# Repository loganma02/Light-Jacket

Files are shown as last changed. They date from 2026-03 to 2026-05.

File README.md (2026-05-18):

# Light Jacket
Person wearing light jacket glowing green while standing in alley

In this project I set out to make a jacket for a costume with which I could change colors and pulse lights in a pattern,
[WLED](https://github.com/WLED/WLED) allowed for app-based control and minimal fiddling once powered on.

## <ins>PCB Update Mid May 2026 </ins>
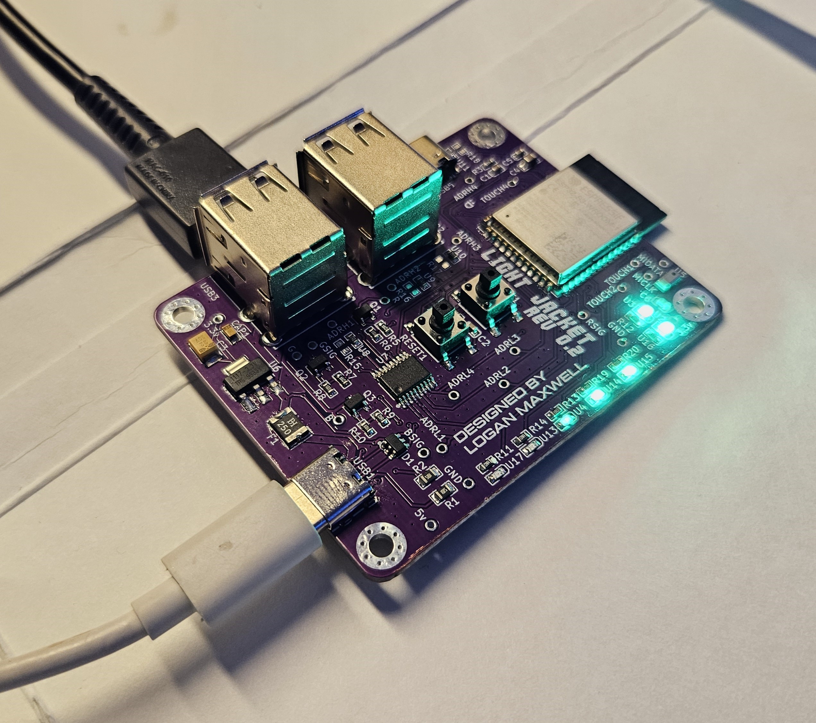
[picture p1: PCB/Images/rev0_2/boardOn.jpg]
light jacket board with lights on (https://youtu.be/194a6y9pxL4)

[See it in action here!](https://youtu.be/194a6y9pxL4)
<table>
  <tr>
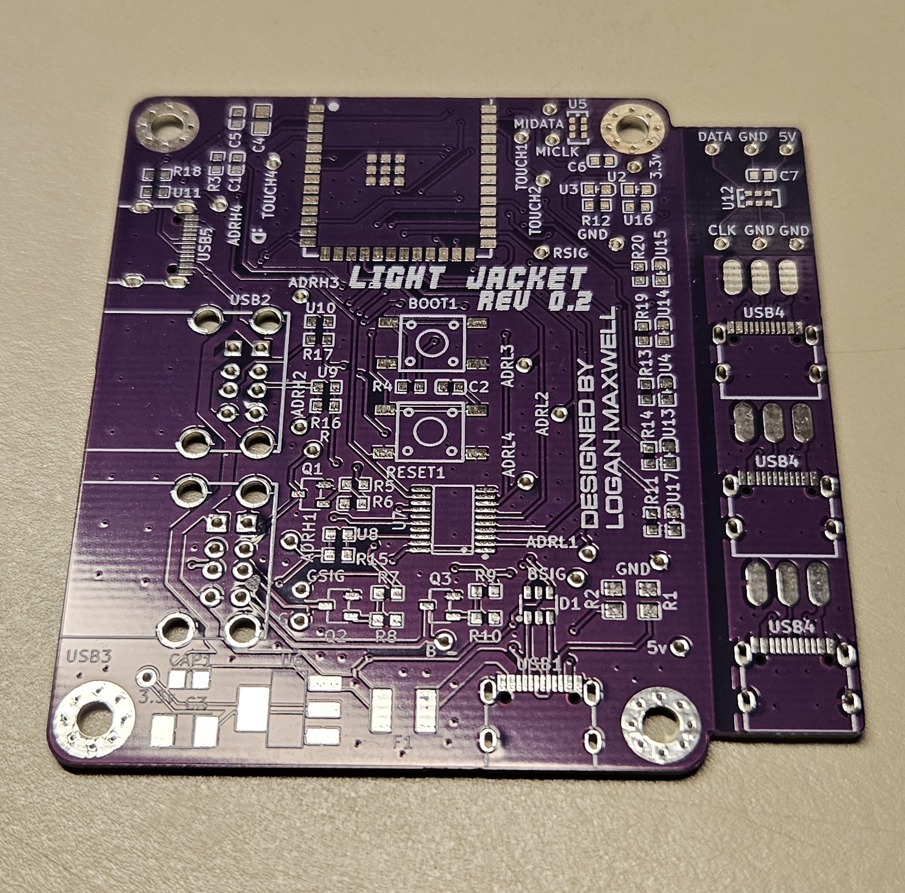
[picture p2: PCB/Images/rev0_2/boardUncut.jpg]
New board with breakouts attached
    <td></td>
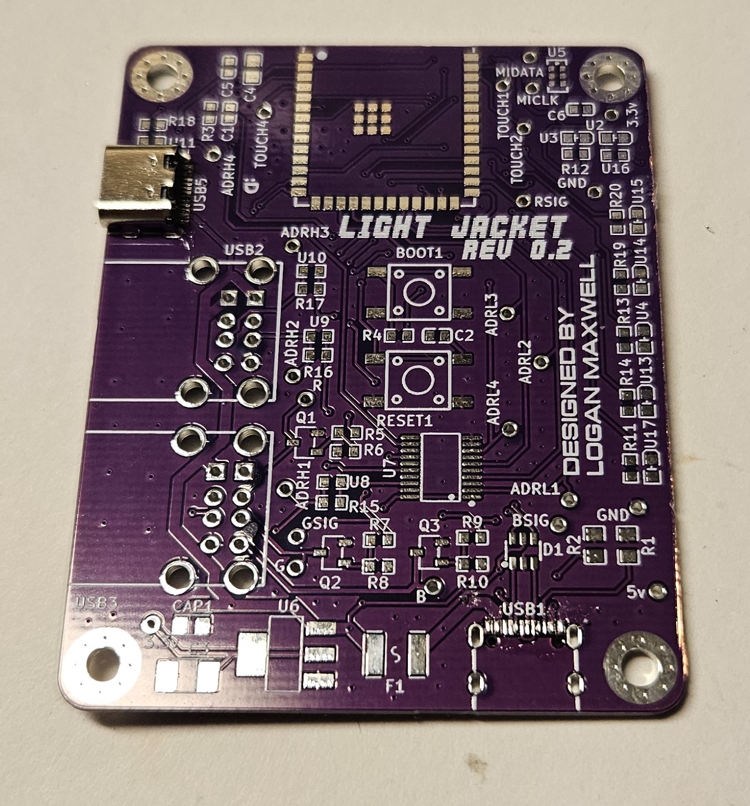
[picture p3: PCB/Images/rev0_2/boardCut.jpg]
New board with breakouts removed
    <td></td>
  </tr>
</table>

This revision arrived and looks great with the purple silkscreen. Trying the score and snap proved difficult due to the copper pour over the region, but tin shears made easy work of cutting off the breakout boards.

With the breakout board I made to attach to an addressable strip using USB-C I flipped the power and ground connections from what I intended, I wanted to sandwich the solder between the board and the strip. Nonetheless it feels much sturdier than soldering individual wires cut from the inside of a cable, and looks a lot cleaner too.
The USB-C connector on the board for output works quite well, if I switch away from USB-A I could shrink the vertical footprint too.

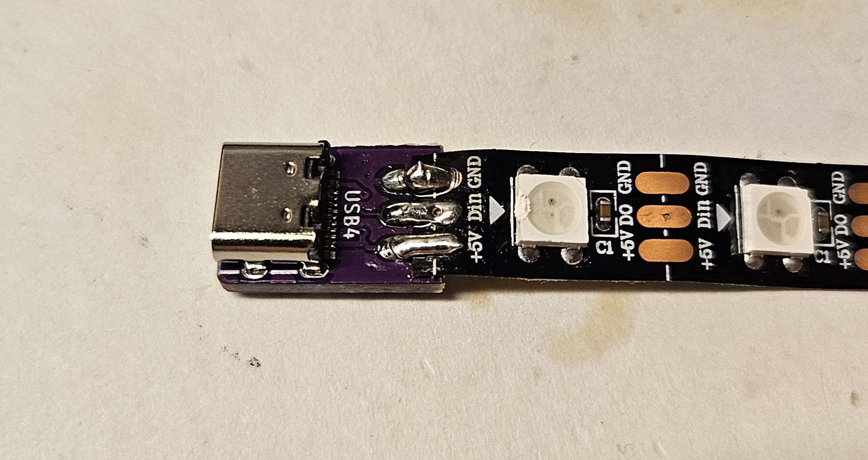
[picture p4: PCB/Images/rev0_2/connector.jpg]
closeup of usbc breakout board


The microphone remains to be working even with an added decoupling capacitor near its power input. There is a breakout board where I'll use a different microcontroller to test its function, perhaps it just isn't compatible with WLED as is.

The 5 onboard LEDs available to control came only from having an abundance of GPIO pins leftover, but I find them to be a nice touch. WLED can easily bundle them into a segment to display effects. Perhaps they could be used to show information to justify their placement beyond aesthetics, but even without I think the small increase in BOM cost is worth it.

## <ins>PCB Update Mid April 2026 </ins>
Taking into account some of the problems with the board as it was:
* Addressable LED control not working as expected
* [No resistor on the LED data lines](https://quinled.info/data-signal-cable-conditioning/)
* No testing pads for 5v LED signals
* Microphone not working
* USB-A ports too close together for thick plugs
* UCB-C port in wrong corner for intended use with power bank
* Only one controllable onboard LED
* Unrounded corners

I decided to design another revision, this time in KiCad to further my skills with that software. Using the [LCSC library loader](https://github.com/dsa-t/jlc-kicad-lib-loader) addon bringing footprints and step models from my EasyEDA design was easy, and reconstructing the schematic in KiCad took only a little while.
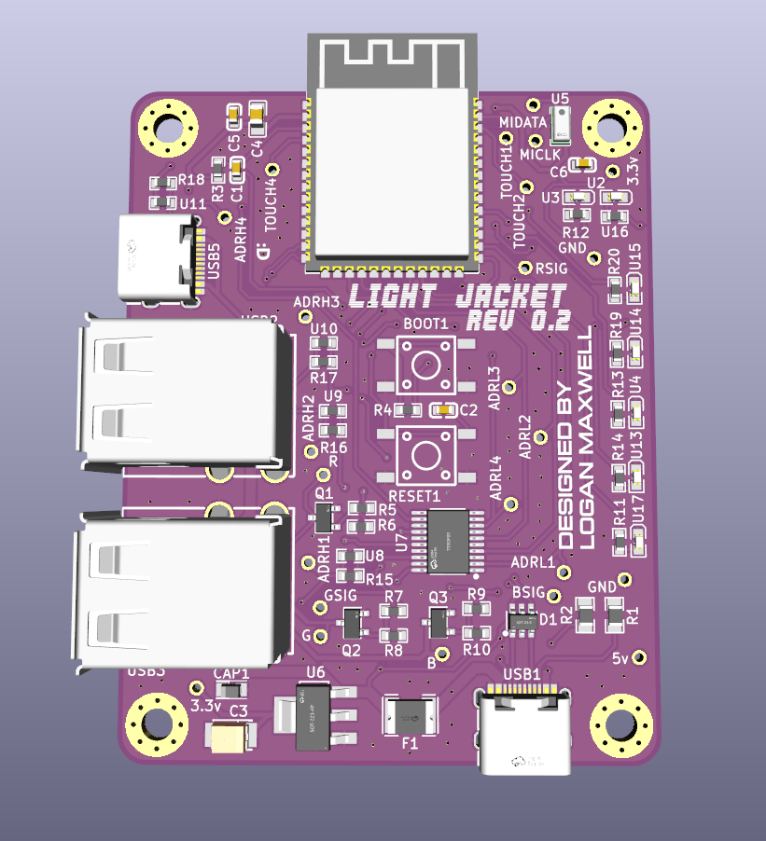
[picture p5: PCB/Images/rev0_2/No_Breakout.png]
No breakout version of board


I realized while designing I wanted breakout boards for testing the microphone on its own, as well as USB-C boards with pads that match the size and layout of the strip. I used mousebites provided by [Panelization.pretty](https://github.com/madworm/Panelization.pretty) to add those breakouts to the side of the main board:
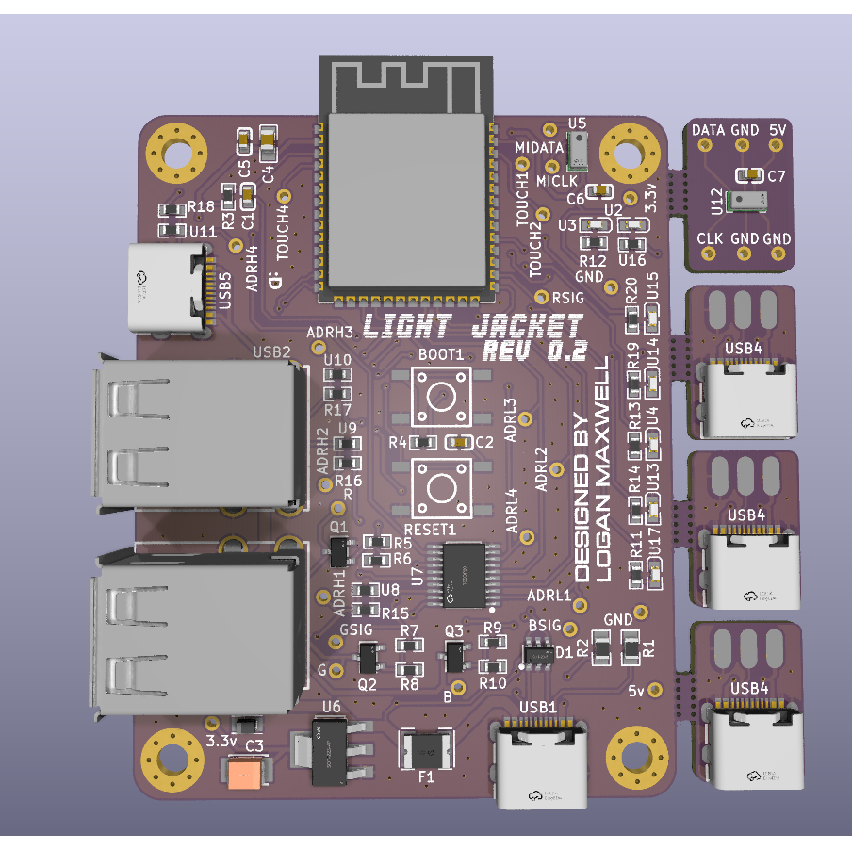
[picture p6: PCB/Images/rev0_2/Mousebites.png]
Mousebites version of the board


Unfortunately this was rejected by JLCPCB as containing too many individual designs to quality for lower manufacturing costs, likely due to extra care needed in handling panelized boards. I instead decided to make the breakouts contained within the same shape as the main board (which JLCPCB did accept) and will use the score-and-snap method to separate them when it arrives.
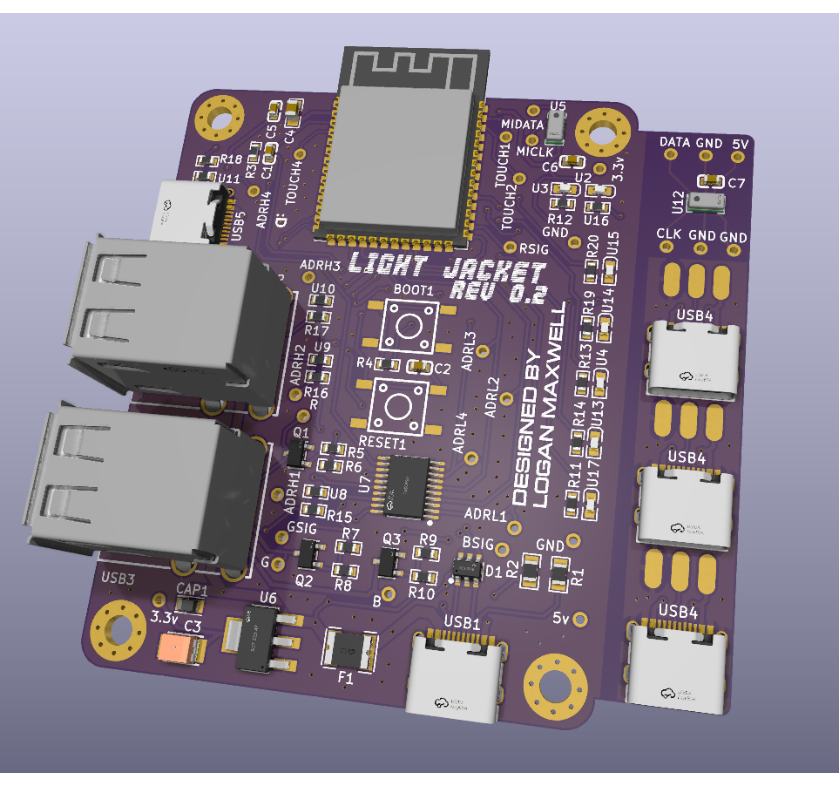
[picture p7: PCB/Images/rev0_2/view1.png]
View 1

<table>
  <tr>
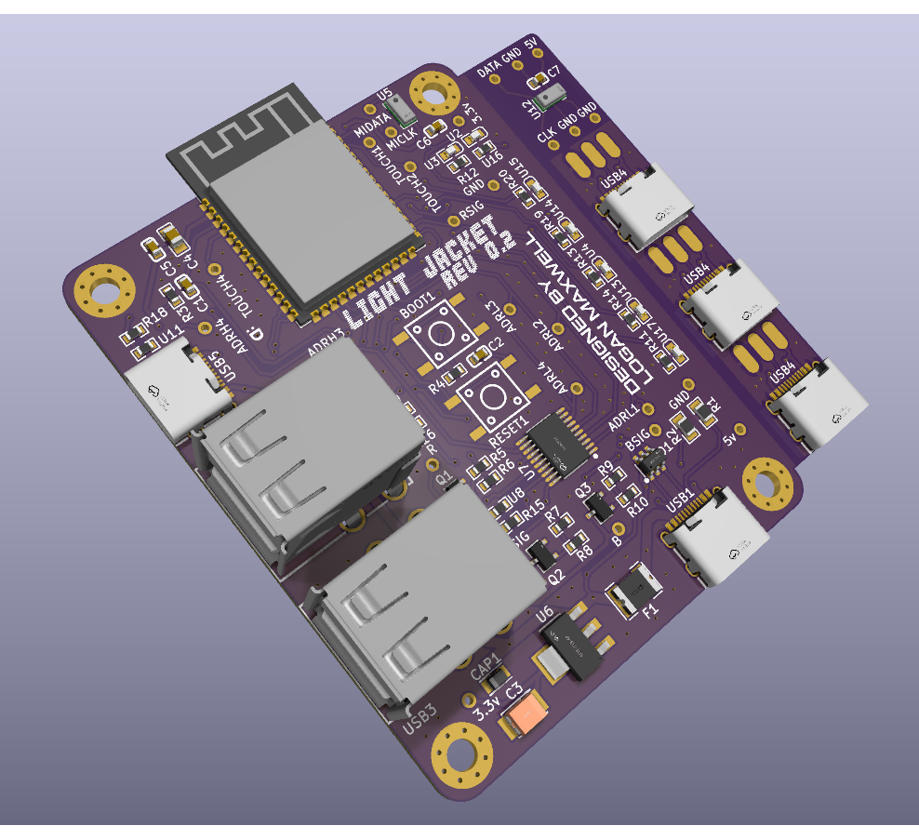
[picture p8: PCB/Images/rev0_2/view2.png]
View 2
    <td></td>
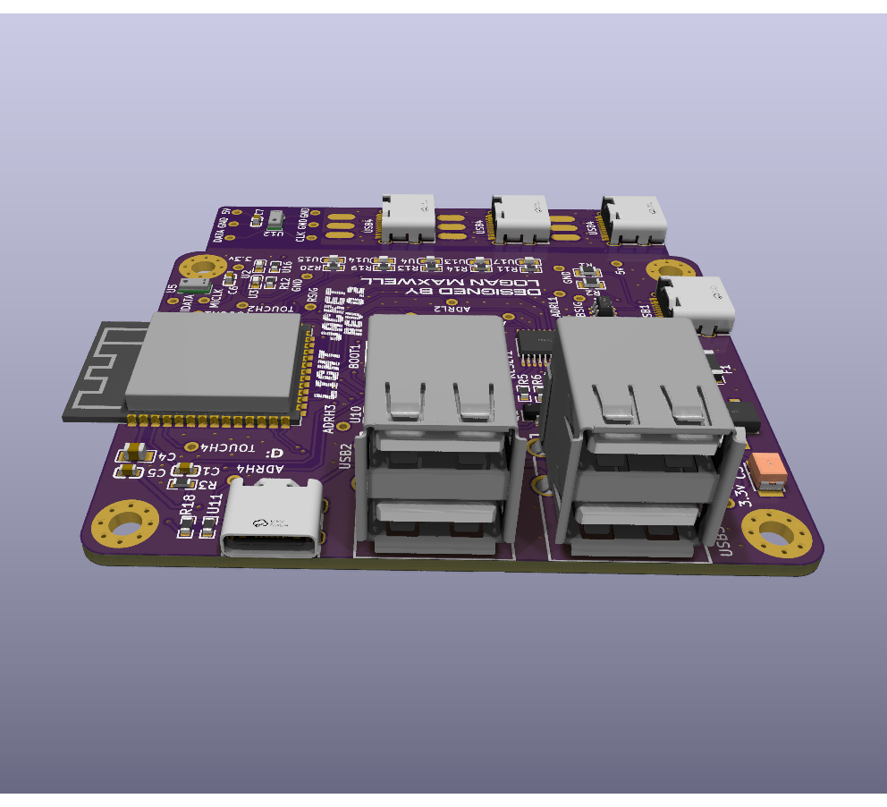
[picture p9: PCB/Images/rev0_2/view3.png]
View 3
    <td></td>
  </tr>
</table>

## <ins>PCB Update Early April 2026 </ins>
The first revision of the PCB arrived and came out of JLCPCB fab better than expected. I was a little bit worried about silkscreen readability as text 0.15mm stroke width was ever so slightly below their [manufacturing capabilities](https://jlcpcb.com/capabilities/pcb-capabilities), but it came through perfectly readable.
<table>
  <tr>
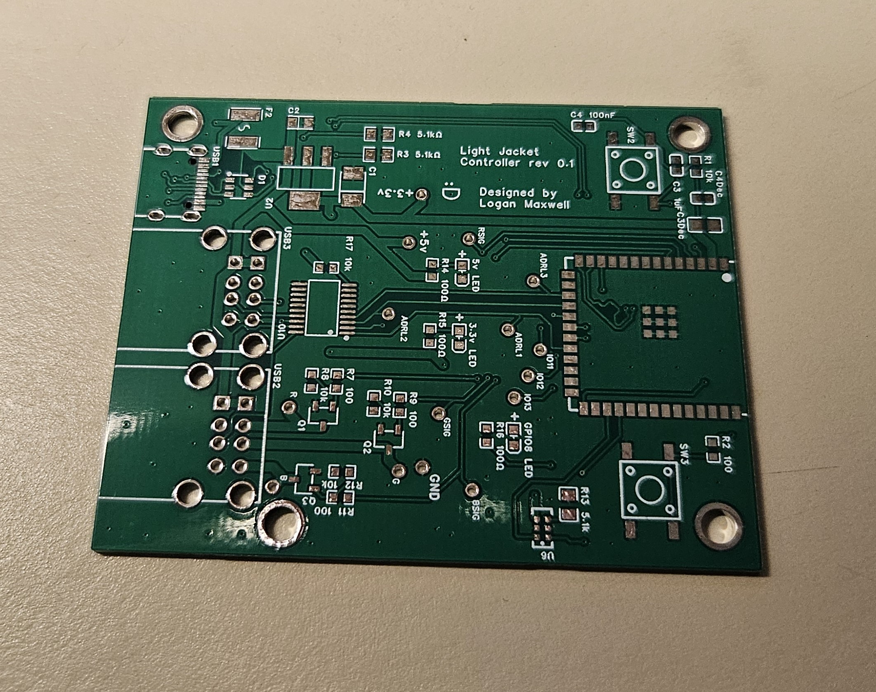
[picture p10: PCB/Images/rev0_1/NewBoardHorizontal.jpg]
New board place horizontally
    <td></td>
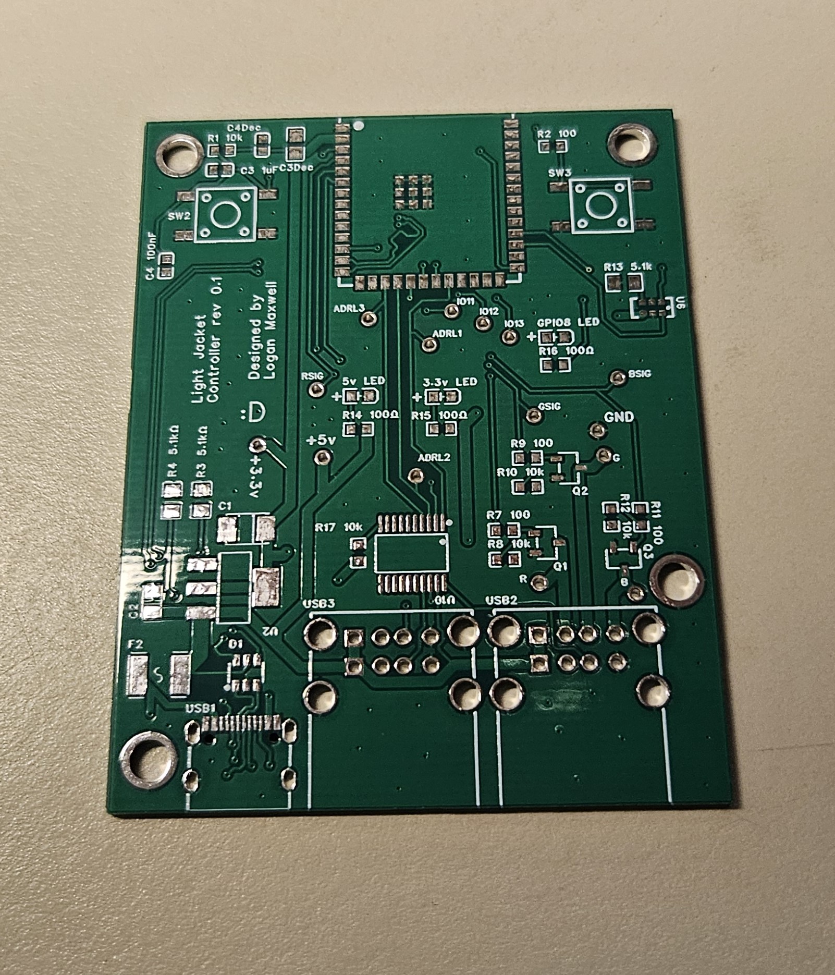
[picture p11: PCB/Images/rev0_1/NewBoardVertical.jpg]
New board place vertically
    <td></td>
  </tr>
</table>

Soldering was relatively easy if not time-consuming, as this was my first experience with hor air reflow soldering for SMD components.
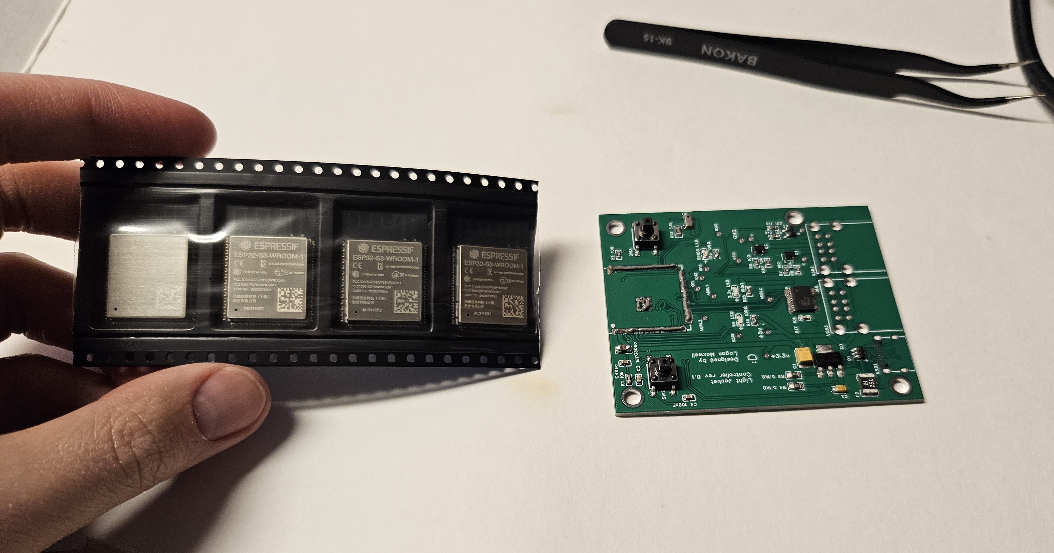
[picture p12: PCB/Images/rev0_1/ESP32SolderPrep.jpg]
Ready to solder ESP32

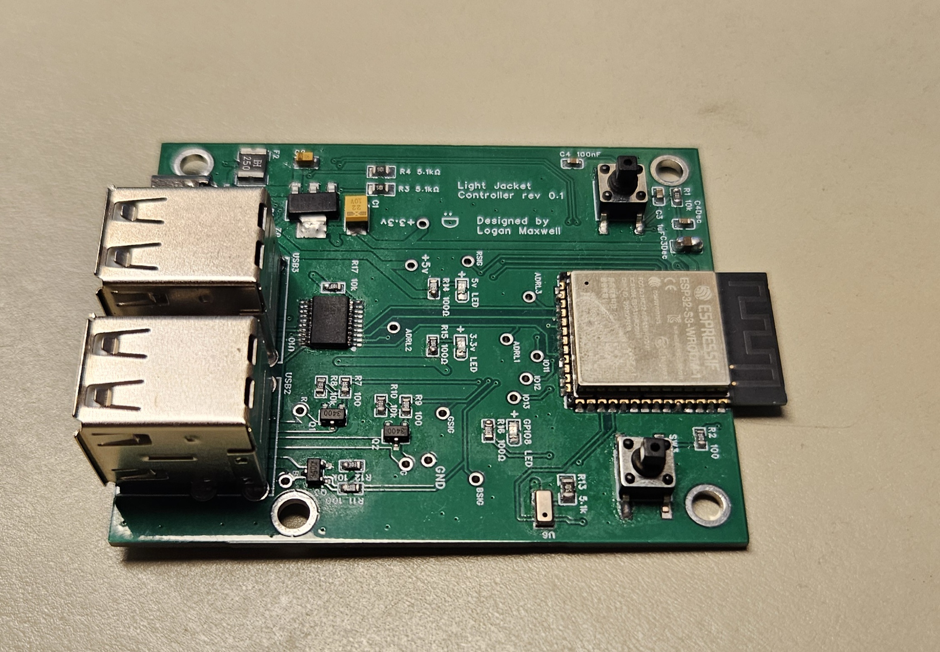
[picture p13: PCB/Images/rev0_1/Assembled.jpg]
Assembled Board


Once assembled I could verify that both my 3.3v and 5v power rails were functioning with both LED's lighting up, and went ahead and installed WLED v16 on it through USB. The PWM RGB strip control worked without a hitch, and could drive an LED strip with a common voltage and individual color grounds.
Working with single color

I did run into a problem with addressable strip control where I would get a randomly blinking mess. See it here:
<details> 
  <summary>Caution: Flashing Lights</summary>

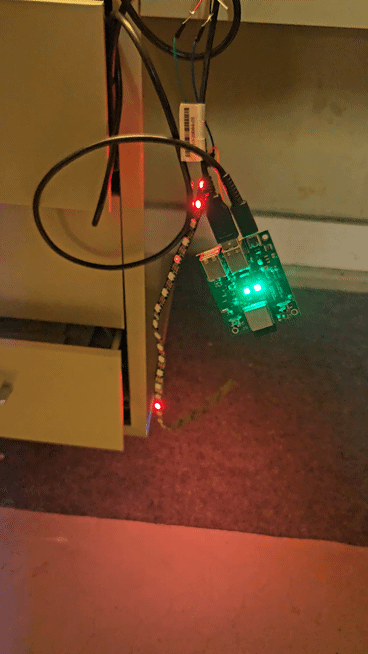
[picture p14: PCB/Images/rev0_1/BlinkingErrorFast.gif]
Addressable led control flashing error
    
</details>

I don't have an oscilloscope to be able to test and see what's happening to the signal, but some research leads me to believe it might have to do with the way I'm using the TXS0108EPWR for level shifting. It seems to be designed more for high-speed onboard signal shifting whose output runs [less than 6 inches](https://learn.sparkfun.com/tutorials/level-shifter---8-channel-txs0108e-hookup-guide/all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,level%20shifters.).
The bi-directionality of the TXS0108EPWR could mean that it's picking up noise on the "output" that triggers it to switch directions and start communicating in the wrong direction.
Letting the supply voltage and ground travel though a USB cable while connecting the data line straight to a 3.3v signal output (which should be too low for the WS2812b) from the ESP32 made it work no problem.

## <ins>PCB Update March 2026 </ins>
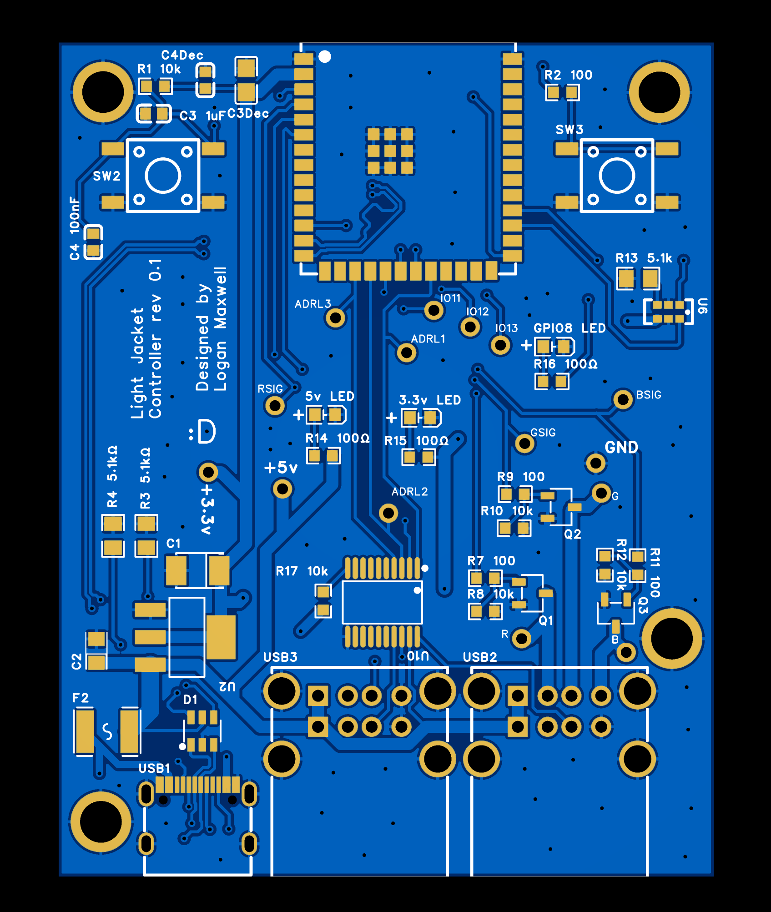
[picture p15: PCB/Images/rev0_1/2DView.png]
PCB 2D View

Currently awaiting delivery of a prototype PCB board for this jacket. Using an ESP32-S3 and a digital microphone to make audio reactivity possible with WLED.
Chose to use USB-C for programming and power due to availability of cables, and the USB-A plug (but not the full standard) for the connection to the lights. Exploring USB-C plug or magnetic connectors for this purpose.
Gerber files can be found [here](PCB/LightJacketV0.1.zip).
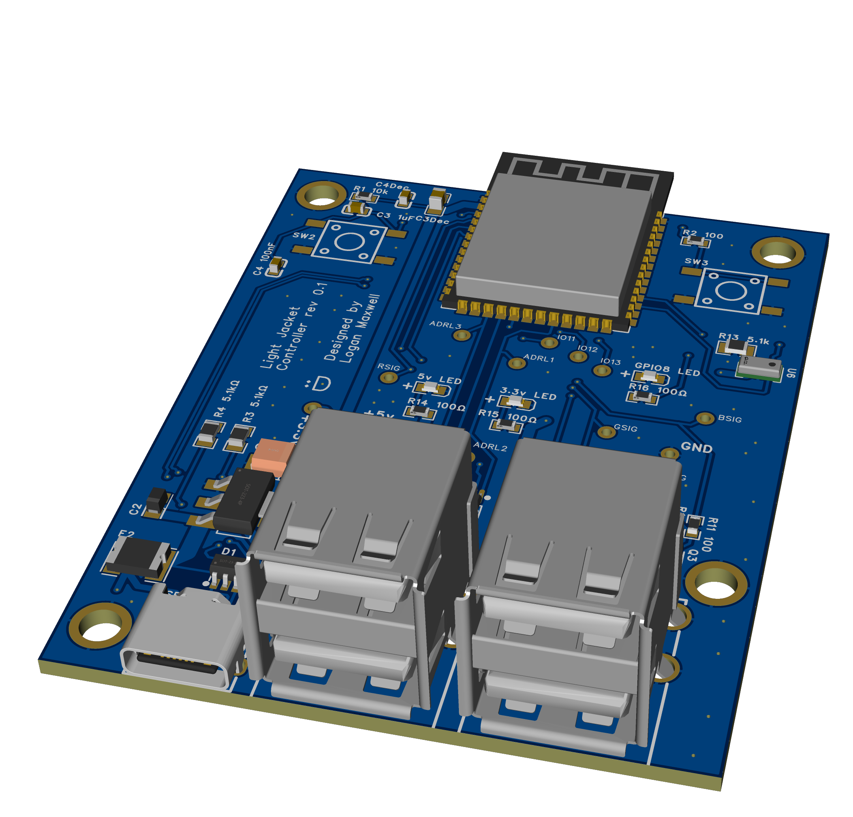
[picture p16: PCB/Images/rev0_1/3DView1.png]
PCB 3D View 1

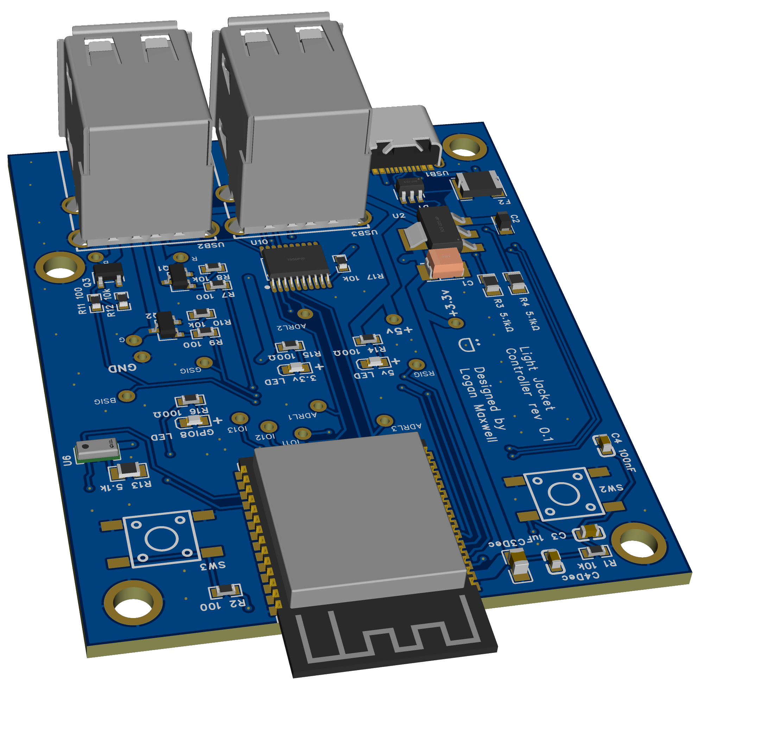
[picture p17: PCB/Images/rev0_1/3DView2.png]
PCB 3D View 2


## Jacket Construction
Jacket unfurled showing strip and circuit board

The strip runs hidden along the inside next to the zipper for an ambient lighting effect, and visible around the collar for the exposed design choice.
The battery and circuit board tuck into an existing pocket on the inside.

Inside of jacket showing LED strip sewn in
I decided to sew in the strip for durability rather than use adhesive, and tried to match existing seam lines.

## Circuitry
I used an ESP8266 and a single color RGB LED strip as that's what I had on hand, but opting for a ESP32 increases options available for WLED, and addressable LED strips allow for more impressive patterns to be displayed.
WLED has an option to control single color strips with PWM signals for each RGB channel, and I fed signal each into a transistor to boost the power for that channel.
Power is supplied by a phone battery bank connected by a USB cable spliced to provide 5V to the ESP as well as each transistor. 
3 transistors visible on perfboard with wires visible leading to power bank and LED strip
*Transistor side of perfboard*

ESP8266 soldered to perfboard
*ESP8266 on perfboard*

## Next steps
I would like to upgrade the microcontroller to an ESP32 and add a microphone, as WLED has better support for audio reactivity on that board.
Ultimately want the jacket to react to sounds, such as pulsing along to the beat of music on a dancefloor, or visually alerting the user to a dangerously loud environment.

## Images
Jacket worn, illuminated green
Jacket worn, illuminated blue
Light Jacket illuminated blue laid out on table

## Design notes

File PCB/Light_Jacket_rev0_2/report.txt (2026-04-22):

Plotted to 'C:\Users\logan\Documents\KiCad\ESP32 Tutorial S3\Light_Jacket_rev0_2\Output\Light_Jacket_rev0_2-F_Cu.gbr'.
Plotted to 'C:\Users\logan\Documents\KiCad\ESP32 Tutorial S3\Light_Jacket_rev0_2\Output\Light_Jacket_rev0_2-B_Cu.gbr'.
Plotted to 'C:\Users\logan\Documents\KiCad\ESP32 Tutorial S3\Light_Jacket_rev0_2\Output\Light_Jacket_rev0_2-F_Paste.gbr'.
Plotted to 'C:\Users\logan\Documents\KiCad\ESP32 Tutorial S3\Light_Jacket_rev0_2\Output\Light_Jacket_rev0_2-B_Paste.gbr'.
Plotted to 'C:\Users\logan\Documents\KiCad\ESP32 Tutorial S3\Light_Jacket_rev0_2\Output\Light_Jacket_rev0_2-F_Silkscreen.gbr'.
Plotted to 'C:\Users\logan\Documents\KiCad\ESP32 Tutorial S3\Light_Jacket_rev0_2\Output\Light_Jacket_rev0_2-B_Silkscreen.gbr'.
Plotted to 'C:\Users\logan\Documents\KiCad\ESP32 Tutorial S3\Light_Jacket_rev0_2\Output\Light_Jacket_rev0_2-F_Mask.gbr'.
Plotted to 'C:\Users\logan\Documents\KiCad\ESP32 Tutorial S3\Light_Jacket_rev0_2\Output\Light_Jacket_rev0_2-B_Mask.gbr'.
Plotted to 'C:\Users\logan\Documents\KiCad\ESP32 Tutorial S3\Light_Jacket_rev0_2\Output\Light_Jacket_rev0_2-Edge_Cuts.gbr'.
Created Gerber job file 'C:\Users\logan\Documents\KiCad\ESP32 Tutorial S3\Light_Jacket_rev0_2\Output\Light_Jacket_rev0_2-job.gbrjob'.
Info: Done.
Info: Done.

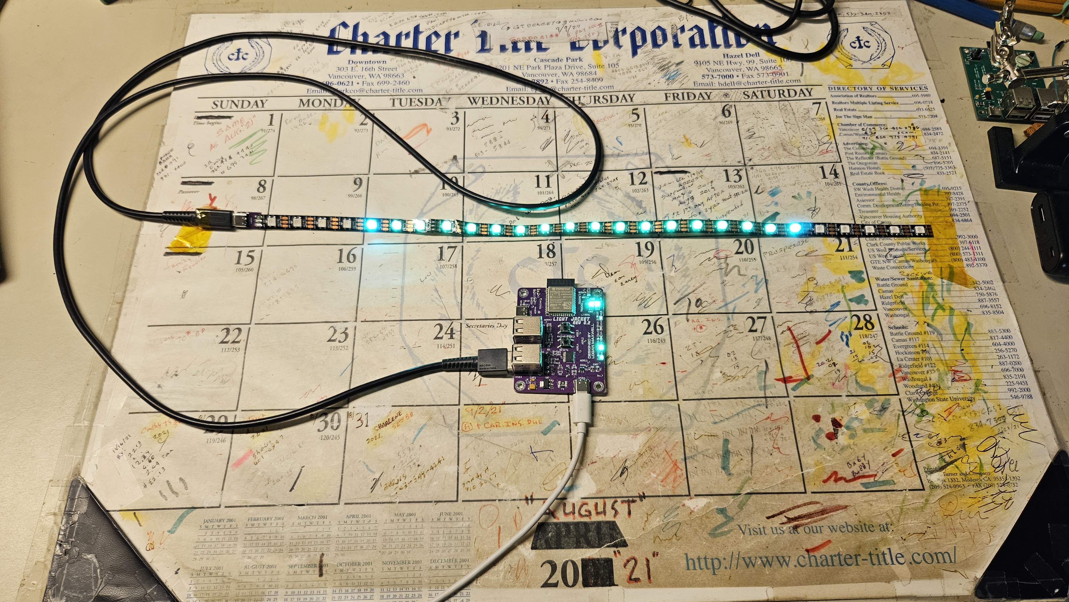
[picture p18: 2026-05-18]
PCB/Images/rev0_2/overview.jpg

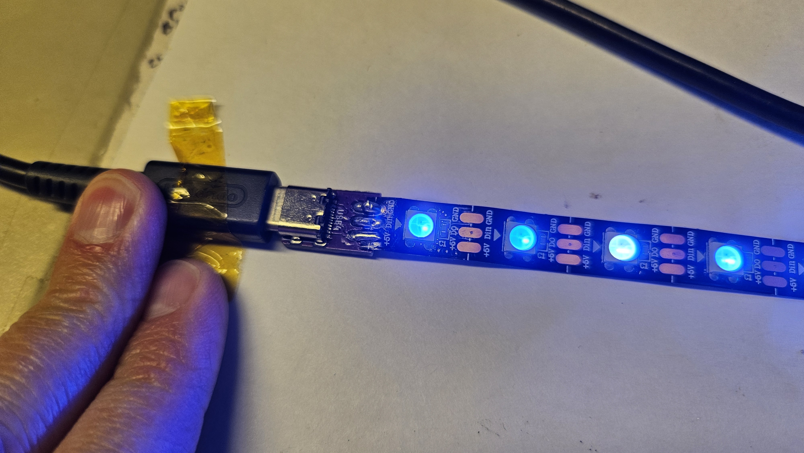
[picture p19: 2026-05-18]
PCB/Images/rev0_2/connectorLit.jpg

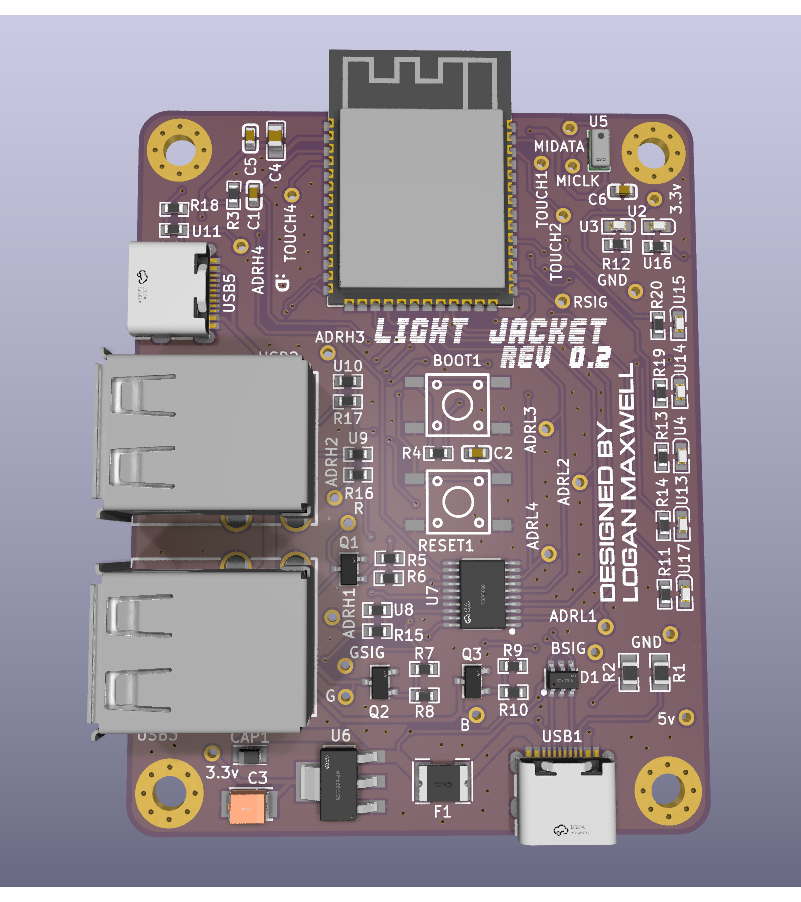
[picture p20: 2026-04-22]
PCB/Images/rev0_2/No_Breakout2.png

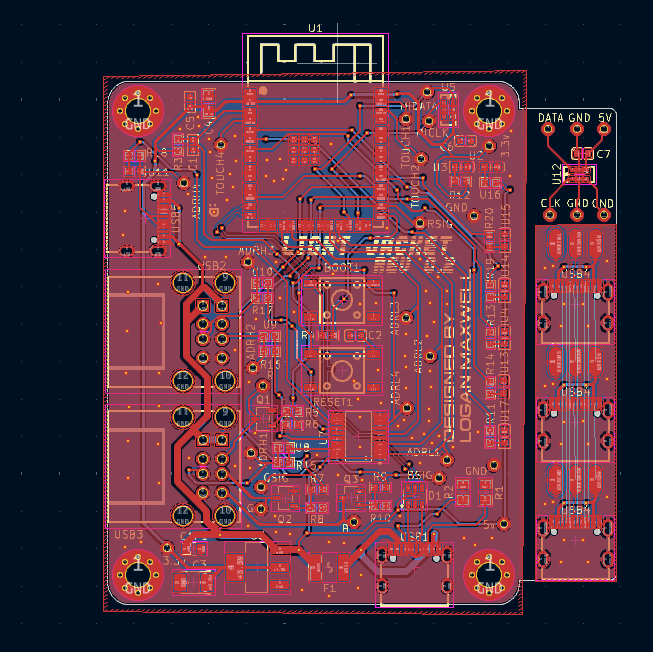
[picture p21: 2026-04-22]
PCB/Images/rev0_2/KicadLayout.png

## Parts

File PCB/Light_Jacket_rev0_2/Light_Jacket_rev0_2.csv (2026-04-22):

Reference | Qty | Value | DNP | Exclude from BOM | Exclude from Board | Footprint | Datasheet | Supplier Part | LCSC Part Name
BOOT1,RESET1 | 2 | ~ |  |  |  | EasyEDA_Lib:SW-SMD_4P-L6.0-W6.0-P4.50-LS9.0-H7.3 | https://item.szlcsc.com/datasheet/HX-6x6x7.3-TP%2520FT%2520square%2520button/51650213.html | C49234152 | 6*6*7.3mm贴片 方头 轻触开关
C1 | 1 | 1uF |  |  |  | EasyEDA_Lib:C0603 | https://item.szlcsc.com/datasheet/CL10A105KB8NNNC/16531.html | C15849 | 1uF ±10% 50V
C2,C5,C6,C7 | 4 | 100nF |  |  |  | EasyEDA_Lib:C0603 | https://item.szlcsc.com/datasheet/CC0603KRX7R9BB104/15331.html | C14663 | 100nF ±10% 50V
C3 | 1 | 22uF |  |  |  | EasyEDA_Lib:CAP-SMD_L3.5-W2.8 | https://item.szlcsc.com/datasheet/CA45-B-10V-22uF-K/151738.html | C140412 | 22uF ±10% 10V
C4 | 1 | 22uF |  |  |  | EasyEDA_Lib:C0805 | https://item.szlcsc.com/datasheet/CL21A226MAYNNNE/631473.html | C602037 | 22uF ±20% 25V
CAP1 | 1 | 10uF |  |  |  | EasyEDA_Lib:CAP-SMD_L2.0-W1.3-FD | https://item.szlcsc.com/datasheet/CA45-P-10V-10uF-K/940979.html | C879894 | 10uF ±10% 10V
D1 | 1 | ~ |  |  |  | EasyEDA_Lib:SOT-23-6_L2.9-W1.6-P0.95-LS2.8-BL | https://item.szlcsc.com/datasheet/USBLC6-2SC6/2973336.html | C2827654 | ESD，可防30kV静电
F1 | 1 | ~ |  |  |  | EasyEDA_Lib:F1812 | https://item.szlcsc.com/datasheet/BSMD1812-250-8V/1039127.html | C960027 | 8V 2.5A 1812自恢复
Q1,Q2,Q3 | 3 | ~ |  |  |  | EasyEDA_Lib:SOT-23-3_L3.0-W1.6-P1.90-LS2.8-BR | https://item.szlcsc.com/datasheet/AO3400A/5925703.html | C5224194 | N沟道,电流:5.8A,耐压:30V
R1,R2 | 2 | 5.1kΩ |  |  |  | EasyEDA_Lib:R0805 | https://item.szlcsc.com/datasheet/0805W8F5101T5E/28584.html | C27834 | 5.1kΩ ±1% 125mW 厚膜电阻
R3,R6,R8,R10 | 4 | 10kΩ |  |  |  | EasyEDA_Lib:R0603 | https://item.szlcsc.com/datasheet/FRC0603J103%2520TS/3266960.html | C2930027 | 10kΩ ±5% 100mW 厚膜电阻
R4,R5,R7,R9,R11,R12,R13,R14,R19,R20 | 10 | 100Ω |  |  |  | EasyEDA_Lib:R0603 | https://atta.szlcsc.com/upload/public/pdf/source/20180316/70C0E2BDAE7FCC62C531A5A58D202EE1.pdf | C105588 | 厚膜电阻 100Ω ±1% 100mW
R15,R16,R17,R18 | 4 | 33Ω |  |  |  | EasyEDA_Lib:R0603 | https://item.szlcsc.com/datasheet/RC0603FR-0733RL/109880.html | C108661 | 厚膜电阻 33Ω ±1% 100mW
TP1,TP2,TP3,TP4,TP5,TP6,TP7,TP8,TP9,TP10,TP11,TP12,TP13,TP14,TP15,TP16,TP17,TP18,TP19,TP20,TP21,TP22,TP23,TP24,TP25,TP26,TP27,TP28,TP29,TP30 | 30 | TestPoint |  |  |  | CustomLibrary:EasyEDA Pad | ~
U1 | 1 | 2.4GHz |  |  |  | EasyEDA_Lib:WIRELM-SMD_ESP32-S3-WROOM-1 | https://item.szlcsc.com/datasheet/ESP32-S3-WROOM-1-N16R2/3198303.html | C2913205 | 不带固件 通用型Wi-Fi+低功耗蓝牙MCU模组
U2,U3,U4,U13,U14,U15,U17 | 7 | ~ |  |  |  | EasyEDA_Lib:LED0603-FD | https://item.szlcsc.com/datasheet/YLED0603G/20555405.html | C19273151 | 翠绿色 独立二极管
U5,U12 | 2 | ~ |  |  |  | EasyEDA_Lib:MIC-SMD_6P-L4.0-W2.0_LMD4020T261-OC3 | https://item.szlcsc.com/datasheet/MSM261DGT003/50474176.html | C48227730 | 1.8V 26dB
U6 | 1 | ~ |  |  |  | EasyEDA_Lib:SOT-223-3_L6.5-W3.4-P2.30-LS7.0-BR | https://item.szlcsc.com/datasheet/AMS1117-3.3/19384486.html | C18212698 | 1A低压差线性稳压器
U7 | 1 | ~ |  |  |  | EasyEDA_Lib:TSSOP-20_L6.5-W4.4-P0.65-LS6.4-BL | https://item.szlcsc.com/datasheet/74HCT245PW/54938180.html | C52140501 | 74HCT245PW
U8,U9,U10,U11,U16 | 5 | 249Ω |  |  |  | EasyEDA_Lib:R0603 |  | C2933176 | 249Ω ±1% 100mW 厚膜电阻
USB1,USB4,USB5 | 3 | ~ |  |  |  | EasyEDA_Lib:USB-C_SMD-TYPE-C-31-M-12 | https://item.szlcsc.com/datasheet/USB-TYPE-C-018/3252507.html | C2927038 | Type-C 母 卧贴
USB2,USB3 | 2 | ~ |  |  |  | EasyEDA_Lib:USB-A-TH_AF-SS-JB17.6 | https://item.szlcsc.com/datasheet/AF%2520SS-JB17.6/458828.html | C456021 | Type-A弯插双层母座
C108661 |  |  |  |  |  |  |  | C105588
0 |  |  |  |  |  |  |  | C140412
C52140501 |  |  |  |  |  |  |  | C14663
C2933176 |  |  |  |  |  |  |  | C15849
 |  |  |  |  |  |  |  | C17206
 |  |  |  |  |  |  |  | C18212698
 |  |  |  |  |  |  |  | C19273151
 |  |  |  |  |  |  |  | C27834
 |  |  |  |  |  |  |  | C2827654
 |  |  |  |  |  |  |  | C2913205
 |  |  |  |  |  |  |  | C2927038
 |  |  |  |  |  |  |  | C2930027
 |  |  |  |  |  |  |  | C456021
 |  |  |  |  |  |  |  | C48227730
 |  |  |  |  |  |  |  | C49234152
 |  |  |  |  |  |  |  | C5224194
 |  |  |  |  |  |  |  | C602037
 |  |  |  |  |  |  |  | C879894
 |  |  |  |  |  |  |  | C960027

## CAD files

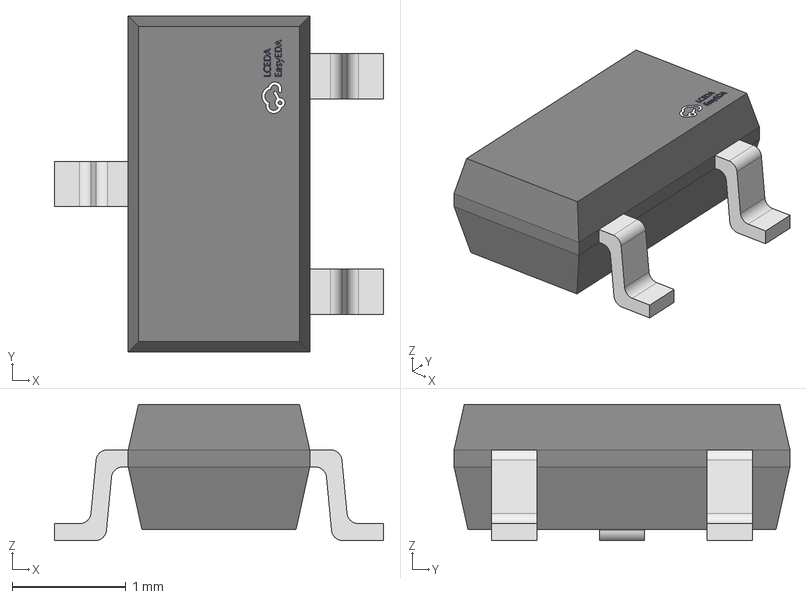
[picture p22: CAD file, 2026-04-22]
PCB/Light_Jacket_rev0_2/EASYEDA_MODELS/SOT-23-3_L3.0-W1.6-P1.90-LS2.8-BR.step
2.90 x 2.96 x 1.20 mm

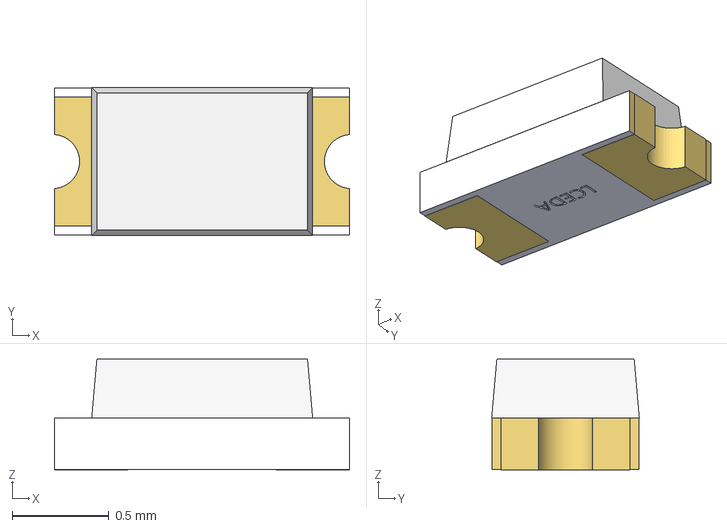
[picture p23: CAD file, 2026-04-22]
PCB/Light_Jacket_rev0_2/EASYEDA_MODELS/LED0603_Inf.step
1.52 x 0.762 x 0.571 mm

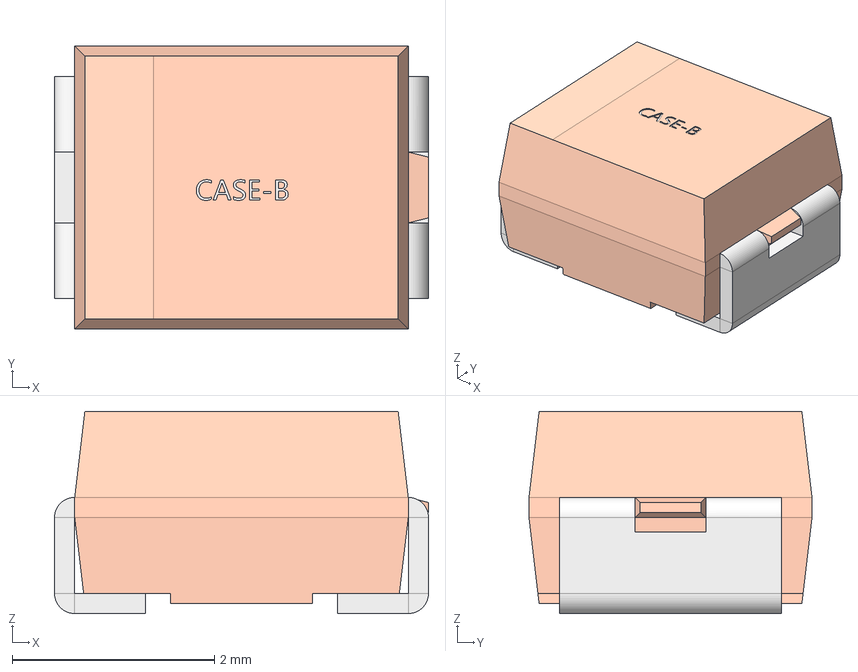
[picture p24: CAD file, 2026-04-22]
PCB/Light_Jacket_rev0_2/EASYEDA_MODELS/CASE-B_L3.5-W2.8-H1.9.step
3.70 x 2.80 x 2.00 mm

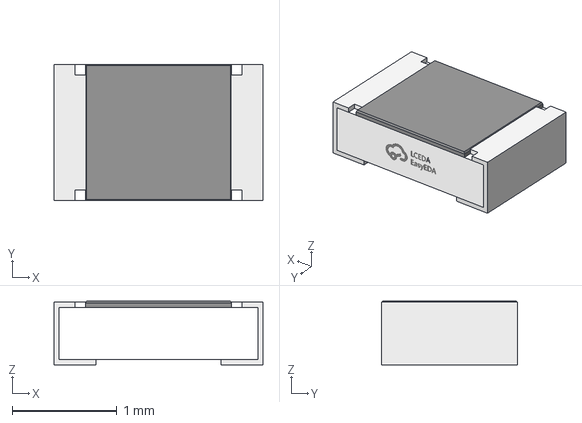
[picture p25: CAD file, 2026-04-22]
PCB/Light_Jacket_rev0_2/EASYEDA_MODELS/R0805_L2.0-W1.3-H0.6.step
2.00 x 1.30 x 0.61 mm

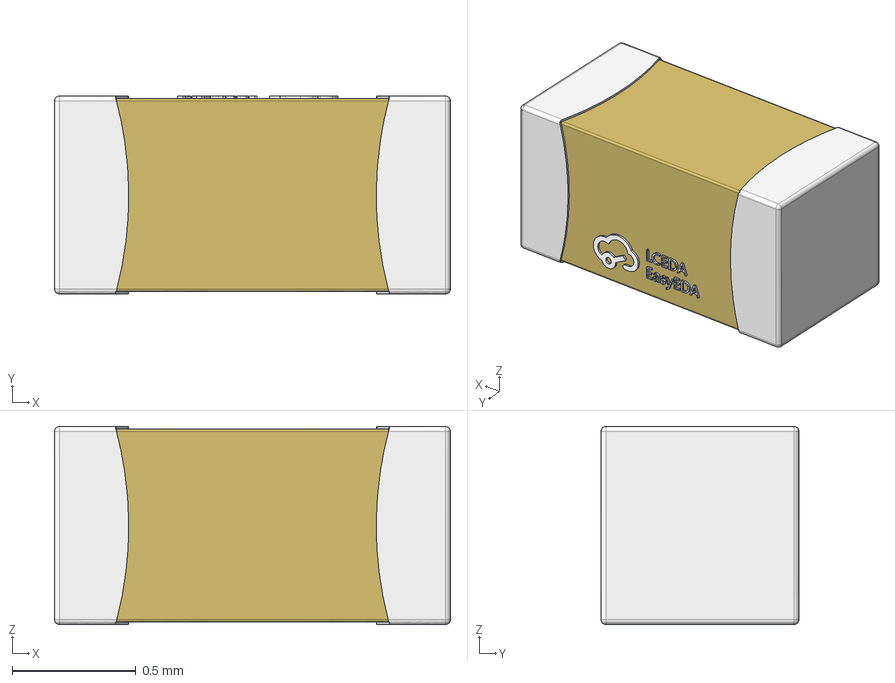
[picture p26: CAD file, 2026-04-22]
PCB/Light_Jacket_rev0_2/EASYEDA_MODELS/C0603_L1.6-W0.8-H0.8.step
1.60 x 0.8 x 0.8 mm

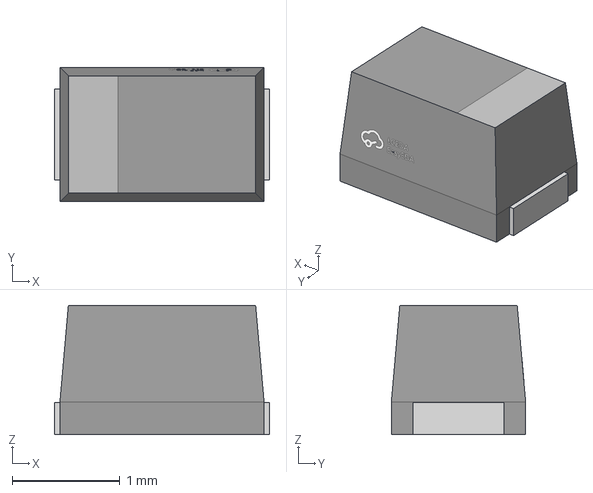
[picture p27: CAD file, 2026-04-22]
PCB/Light_Jacket_rev0_2/EASYEDA_MODELS/CAP-SMD_L2.0-W1.3-FD.step
2.00 x 1.25 x 1.20 mm

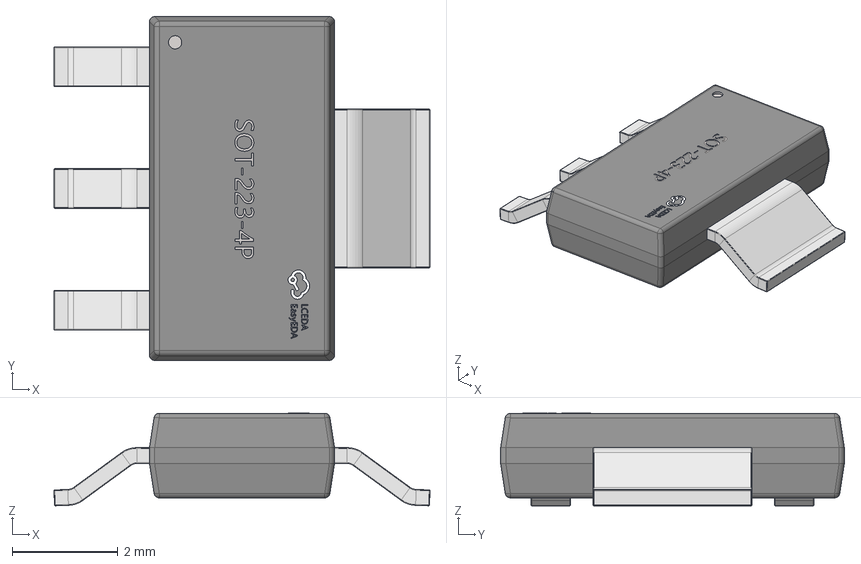
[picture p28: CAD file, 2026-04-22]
PCB/Light_Jacket_rev0_2/EASYEDA_MODELS/SOT-223-4P_L6.5-W3.5-H1.6-LS7.0-P2.30.step
7.11 x 6.50 x 1.75 mm

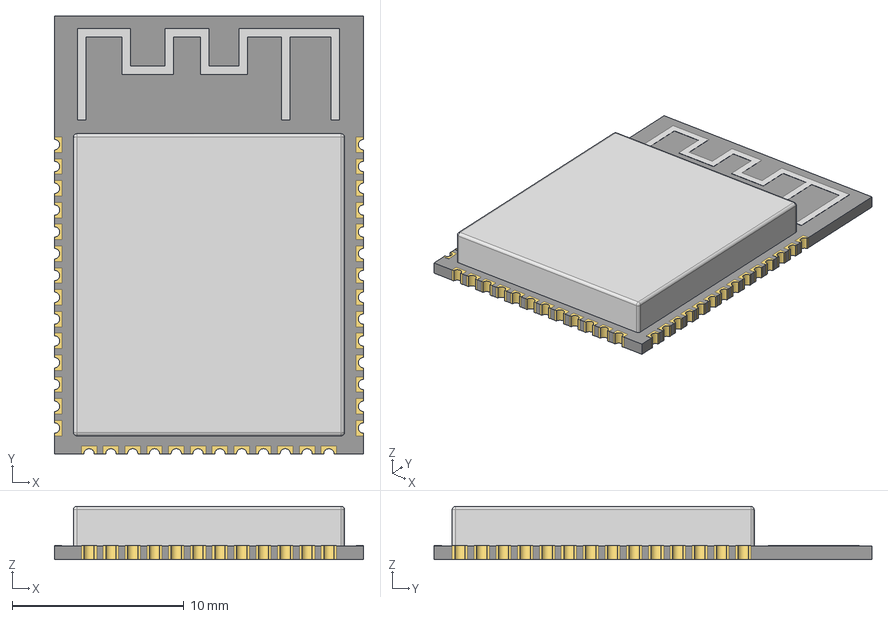
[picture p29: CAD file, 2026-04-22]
PCB/Light_Jacket_rev0_2/EASYEDA_MODELS/WIRELM-SMD_ESP32-S3-WROOM-1.step
18.0 x 25.5 x 3.11 mm

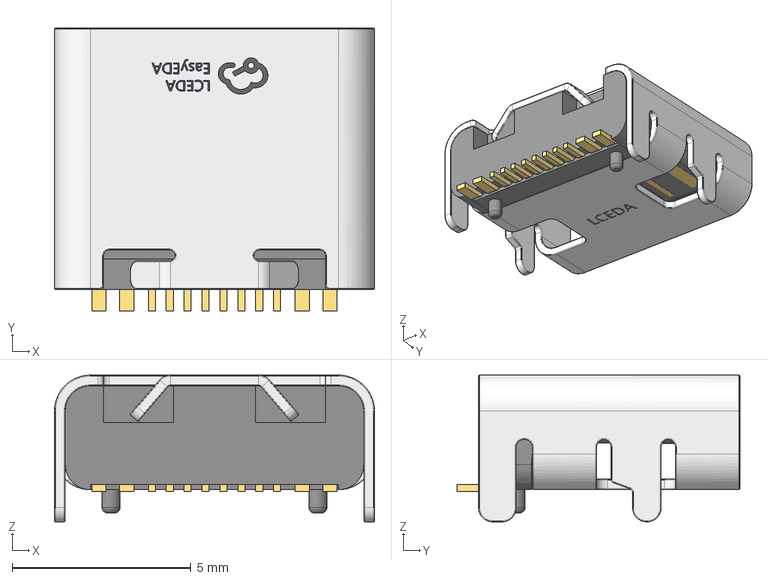
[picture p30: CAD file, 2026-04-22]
PCB/Light_Jacket_rev0_2/EASYEDA_MODELS/USB-C_SMD-TYPE-C-31-M-12.step
8.94 x 7.90 x 4.10 mm

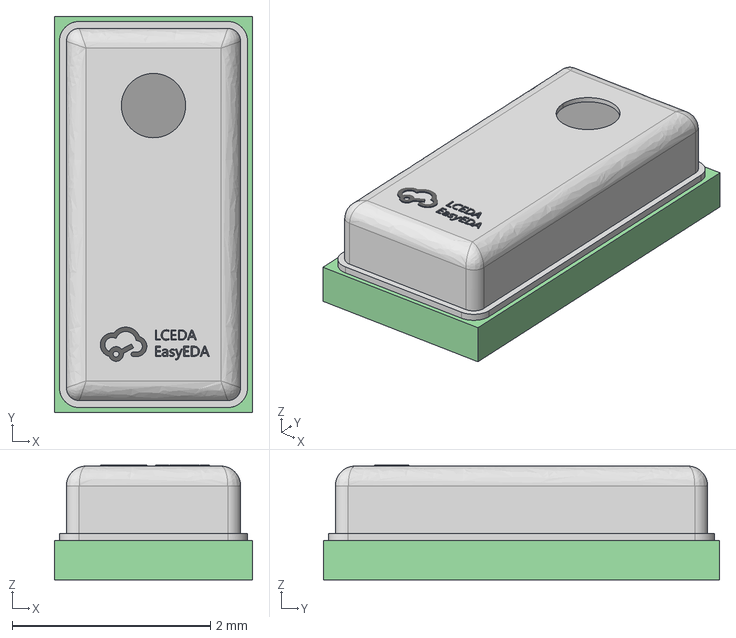
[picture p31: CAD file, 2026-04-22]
PCB/Light_Jacket_rev0_2/EASYEDA_MODELS/MIC-SMD_6P-L4.0-W2.0_LMD4020T261-OC3.step
2.00 x 4.00 x 1.16 mm

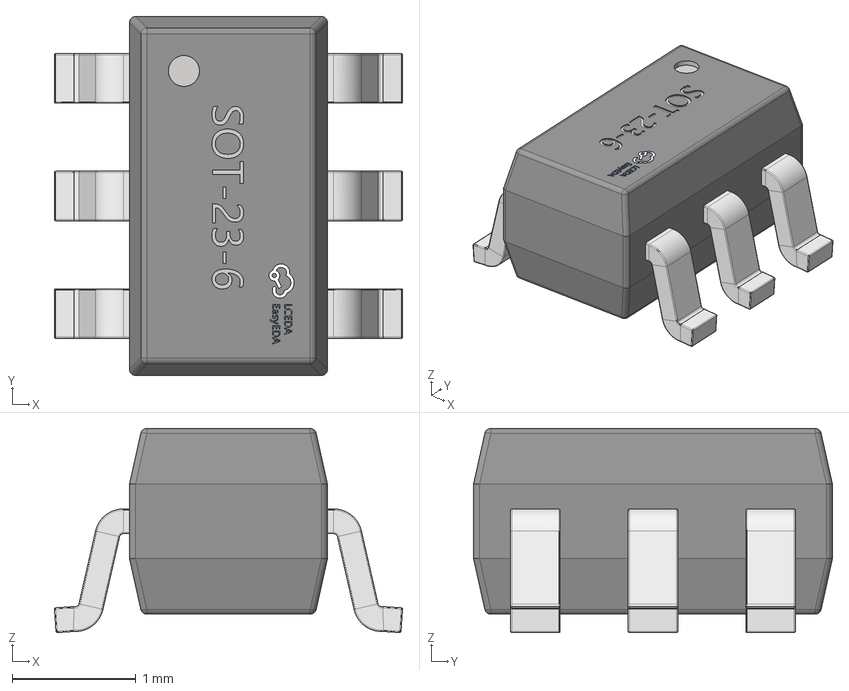
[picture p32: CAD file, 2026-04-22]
PCB/Light_Jacket_rev0_2/EASYEDA_MODELS/SOT-23-6_L2.9-W1.6-H1.5-LS2.8-P0.95.step
2.81 x 2.90 x 1.65 mm

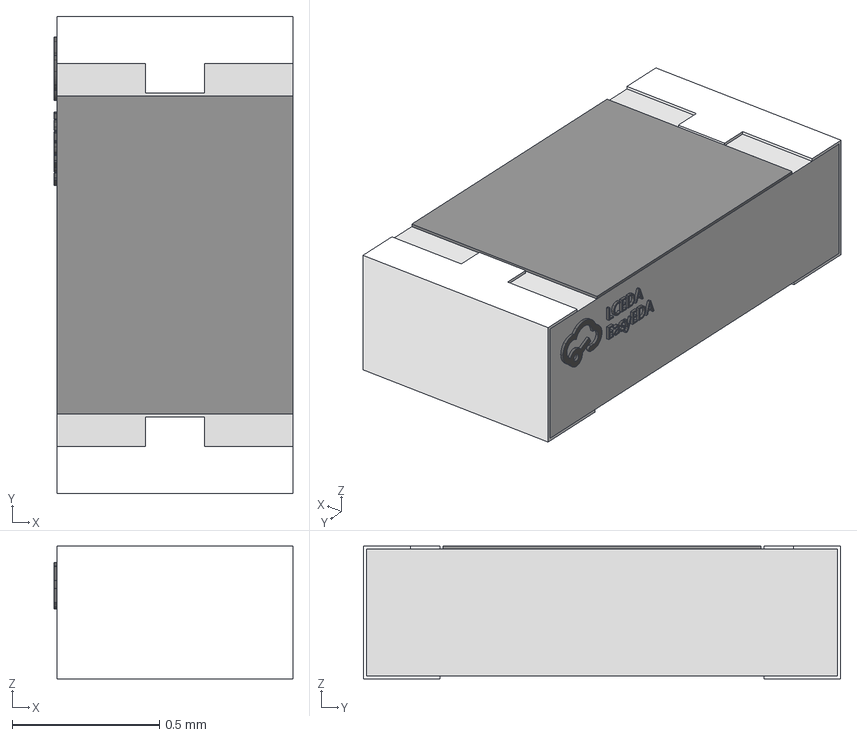
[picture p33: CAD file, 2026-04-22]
PCB/Light_Jacket_rev0_2/EASYEDA_MODELS/R0603.step
0.81 x 1.62 x 0.45 mm

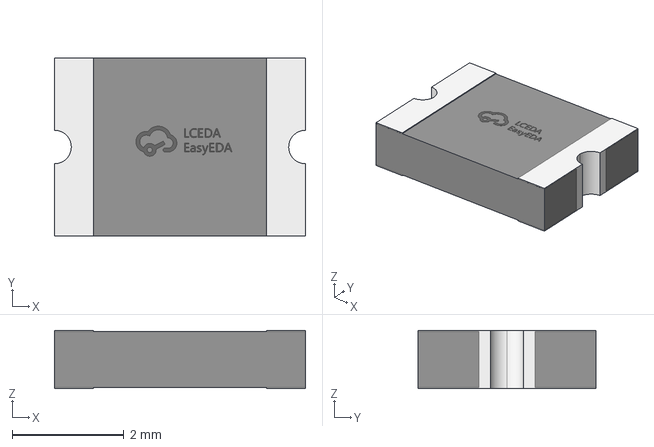
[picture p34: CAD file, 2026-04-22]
PCB/Light_Jacket_rev0_2/EASYEDA_MODELS/F1812_L4.5-W3.2-H1.0.step
4.50 x 3.20 x 1.04 mm

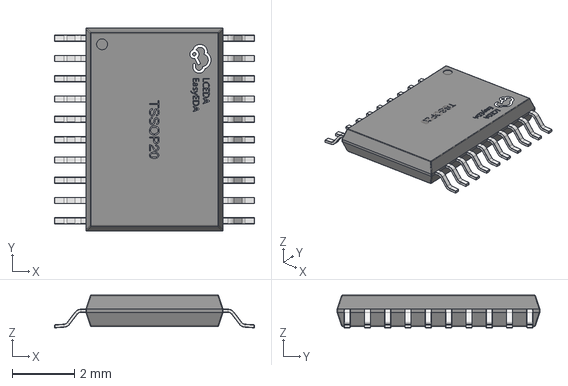
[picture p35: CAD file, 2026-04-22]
PCB/Light_Jacket_rev0_2/EASYEDA_MODELS/TSSOP-20_L6.5-W4.4-H1.0-LS6.4-P0.65.step
6.41 x 6.50 x 1.05 mm

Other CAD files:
PCB/Light_Jacket_rev0_2/EASYEDA_MODELS/C0805_L2.0-W1.3-H1.3.step
PCB/Light_Jacket_rev0_2/EASYEDA_MODELS/USB-A-TH_AF-SS-JB17.6.step

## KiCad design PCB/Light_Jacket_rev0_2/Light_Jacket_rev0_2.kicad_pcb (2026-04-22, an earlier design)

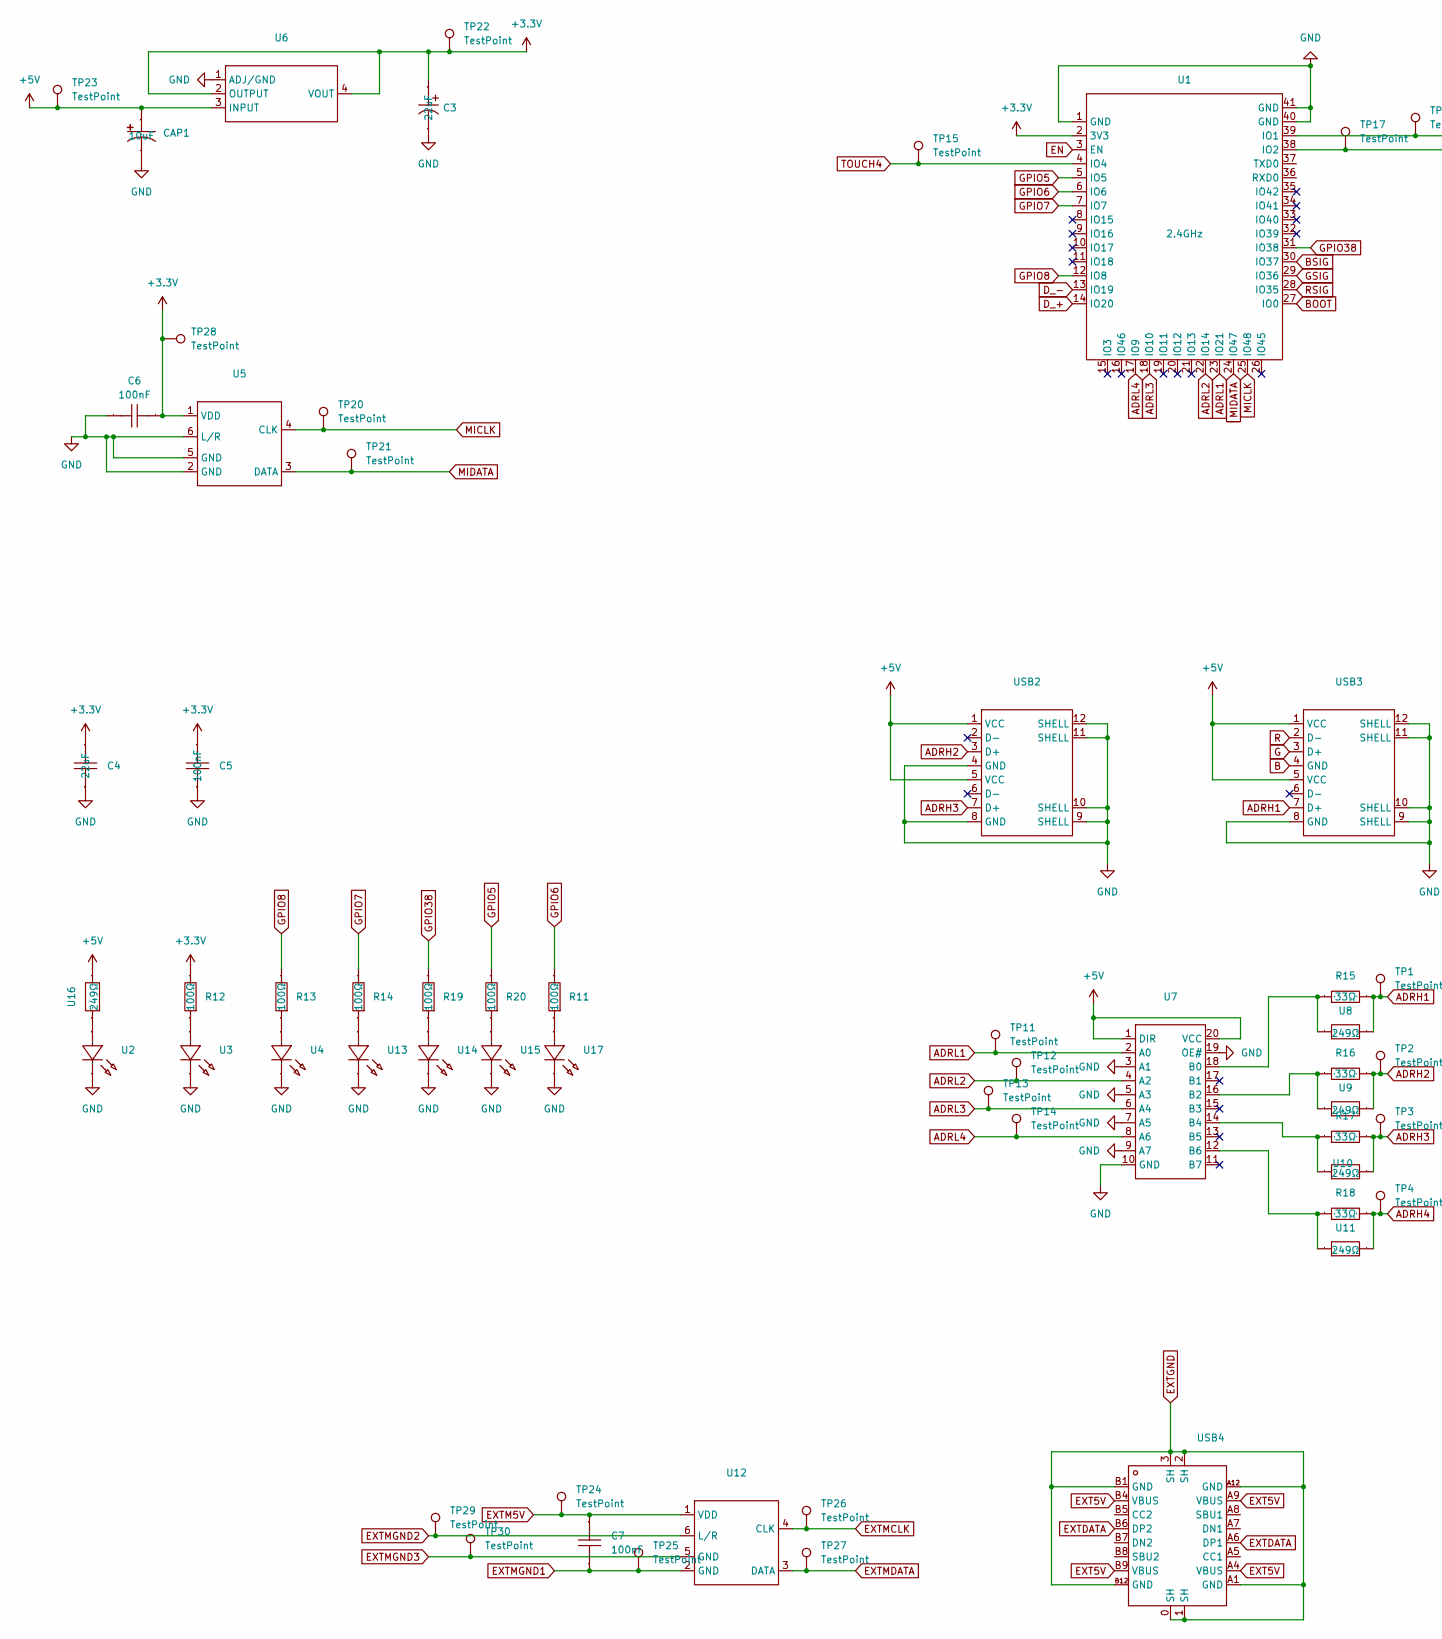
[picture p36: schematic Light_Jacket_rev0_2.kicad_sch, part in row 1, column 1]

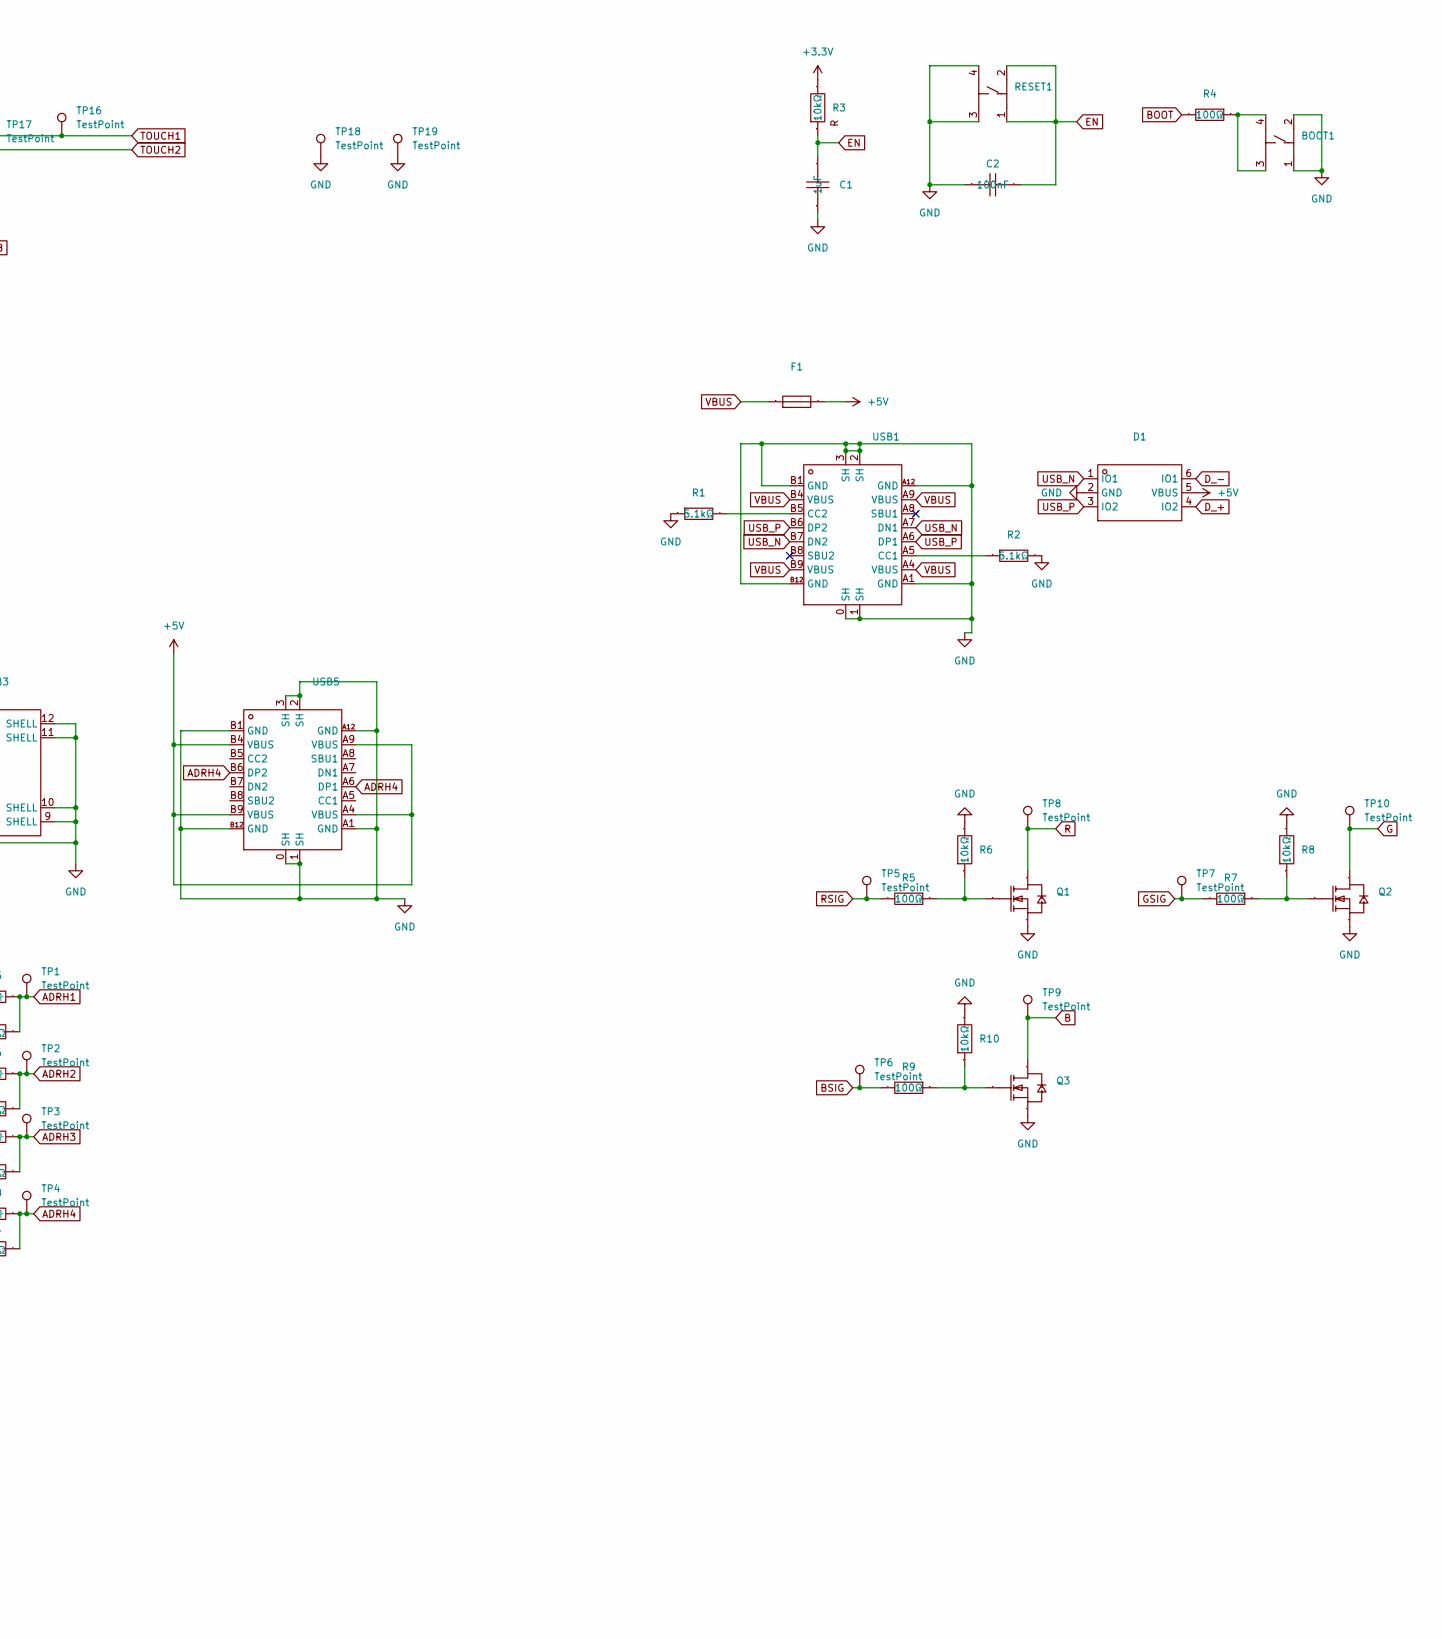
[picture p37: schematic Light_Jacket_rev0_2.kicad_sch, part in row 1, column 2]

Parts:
BOOT1: SW-SMD_4P-L6.0-W6.0-P4.50-LS9.0-H7.3; Manufacturer Part HX-6x6x7.3-TP FT square button; LCSC Part Name 6*6*7.3mm贴片 方头 轻触开关
C1: 1uF; C0603; Manufacturer Part CL10A105KB8NNNC; LCSC Part Name 1uF ±10% 50V
C2, C5, C6, C7: 100nF; C0603; Manufacturer Part CC0603KRX7R9BB104; LCSC Part Name 100nF ±10% 50V
C3: 22uF; CAP-SMD_L3.5-W2.8; Manufacturer Part CA45-B-10V-22uF-K; LCSC Part Name 22uF ±10% 10V
C4: 22uF; C0805; Manufacturer Part CL21A226MAYNNNE; LCSC Part Name 22uF ±20% 25V
CAP1: 10uF; CAP-SMD_L2.0-W1.3-FD; Manufacturer Part CA45-P-10V-10uF-K; LCSC Part Name 10uF ±10% 10V
D1: SOT-23-6_L2.9-W1.6-P0.95-LS2.8-BL; Manufacturer Part USBLC6-2SC6; LCSC Part Name ESD，可防30kV静电
F1: F1812; Manufacturer Part BSMD1812-250-8V; LCSC Part Name 8V 2.5A 1812自恢复
Q1, Q2, Q3: SOT-23-3_L3.0-W1.6-P1.90-LS2.8-BR; Manufacturer Part AO3400A; LCSC Part Name N沟道,电流:5.8A,耐压:30V
R1, R2: 5.1kΩ; R0805; Manufacturer Part 0805W8F5101T5E; LCSC Part Name 5.1kΩ ±1% 125mW 厚膜电阻
R3, R6, R8, R10: 10kΩ; R0603; Manufacturer Part FRC0603J103 TS; LCSC Part Name 10kΩ ±5% 100mW 厚膜电阻
R4, R5, R7, R9, R11, R12, R13, R14, R19, R20: 100Ω; R0603; Manufacturer Part RC0603FR-07100RL; LCSC Part Name 厚膜电阻 100Ω ±1% 100mW
R15, R16, R17, R18: 33Ω; R0603; Manufacturer Part RC0603FR-0733RL; LCSC Part Name 厚膜电阻 33Ω ±1% 100mW
RESET1: SW-SMD_4P-L6.0-W6.0-P4.50-LS9.0-H7.3; Manufacturer Part HX-6x6x7.3-TP FT square button; LCSC Part Name 6*6*7.3mm贴片 方头 轻触开关
TP1, TP2, TP3, TP4, TP5, TP6, TP7, TP8, TP9, TP10, TP11, TP12, TP13, TP14, TP15, TP16, TP17, TP18, TP19, TP20, TP21, TP22, TP23, TP24, TP25, TP26, TP27, TP28, TP29, TP30: TestPoint; EasyEDA Pad
U1: 2.4GHz; WIRELM-SMD_ESP32-S3-WROOM-1; Manufacturer Part ESP32-S3-WROOM-1-N16R2; LCSC Part Name 不带固件 通用型Wi-Fi+低功耗蓝牙MCU模组
U2, U3, U4, U13, U14, U15, U17: LED0603-FD; Manufacturer Part YLED0603G; LCSC Part Name 翠绿色 独立二极管
U5, U12: MIC-SMD_6P-L4.0-W2.0_LMD4020T261-OC3; Manufacturer Part MSM261DGT003; LCSC Part Name 1.8V 26dB
U6: SOT-223-3_L6.5-W3.4-P2.30-LS7.0-BR; Manufacturer Part AMS1117-3.3; LCSC Part Name 1A低压差线性稳压器
U7: TSSOP-20_L6.5-W4.4-P0.65-LS6.4-BL; Manufacturer Part 74HCT245PW; LCSC Part Name 74HCT245PW
U8, U9, U10, U11, U16: 249Ω; R0603; Manufacturer Part FRC0603F2490TS; LCSC Part Name 249Ω ±1% 100mW 厚膜电阻
USB1, USB4, USB5: USB-C_SMD-TYPE-C-31-M-12; Manufacturer Part USB-TYPE-C-018; LCSC Part Name Type-C 母 卧贴
USB2, USB3: USB-A-TH_AF-SS-JB17.6; Manufacturer Part AF SS-JB17.6; LCSC Part Name Type-A弯插双层母座

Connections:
+3.3V: C3.1, C4.2, C5.2, C6.1, R3.2, R12.2, TP22.1, TP28.1, U1.2 (3V3), U5.1 (VDD), U6.2 (OUTPUT), U6.4 (VOUT)
+5V: CAP1.1, D1.5 (VBUS), F1.2, TP23.1, U6.3 (INPUT), U7.1 (DIR), U7.20 (VCC), U16.2, USB2.1 (VCC), USB2.5 (VCC), USB3.1 (VCC), USB3.5 (VCC), USB5.A4 (VBUS), USB5.A9 (VBUS), USB5.B4 (VBUS), USB5.B9 (VBUS)
ADRH1: R15.2, TP1.1, U8.2, USB3.7 (D+)
ADRH2: R16.2, TP2.1, U9.2, USB2.3 (D+)
ADRH3: R17.2, TP3.1, U10.2, USB2.7 (D+)
ADRH4: R18.2, TP4.1, U11.2, USB5.A6 (DP1), USB5.B6 (DP2)
ADRL1: TP11.1, U1.23 (IO21), U7.2 (A0)
ADRL2: TP12.1, U1.22 (IO14), U7.4 (A2)
ADRL3: TP13.1, U1.18 (IO10), U7.6 (A4)
ADRL4: TP14.1, U1.17 (IO9), U7.8 (A6)
B: Q3.3 (D), TP9.1, USB3.4 (GND)
BOOT: R4.2, U1.27 (IO0)
BSIG: R9.2, TP6.1, U1.30 (IO37)
D_+: D1.4 (IO2), U1.14 (IO20)
D_-: D1.6 (IO1), U1.13 (IO19)
EN: C1.2, C2.2, R3.1, RESET1.1 (A), RESET1.2 (B), U1.3 (EN)
EXT5V: USB4.A4 (VBUS), USB4.A9 (VBUS), USB4.B4 (VBUS), USB4.B9 (VBUS); also elsewhere on the board
EXTDATA: USB4.A6 (DP1), USB4.B6 (DP2); also elsewhere on the board
EXTGND: USB4.0 (SH), USB4.1 (SH), USB4.2 (SH), USB4.3 (SH), USB4.A1 (GND), USB4.A12 (GND), USB4.B1 (GND), USB4.B12 (GND); also elsewhere on the board
EXTM5V: C7.1, TP24.1, U12.1 (VDD)
EXTMCLK: TP26.1, U12.4 (CLK)
EXTMDATA: TP27.1, U12.3 (DATA)
EXTMGND1: C7.2, TP25.1, U12.2 (GND)
EXTMGND2: TP29.1, U12.6 (L/R)
EXTMGND3: TP30.1, U12.5 (GND)
G: Q2.3 (D), TP10.1, USB3.3 (D+)
GND: BOOT1.1 (A), BOOT1.2 (B), C1.1, C2.1, C3.2, C4.1, C5.1, C6.2, CAP1.2, D1.2 (GND), Q1.2 (S), Q2.2 (S), Q3.2 (S), R1.1, R2.2, R6.2, R8.2, R10.2, RESET1.3 (C), RESET1.4 (D), TP18.1, TP19.1, U1.1 (GND), U1.40 (GND), U1.41 (GND), U2.2 (-), U3.2 (-), U4.2 (-), U5.2 (GND), U5.5 (GND), U5.6 (L/R), U6.1 (ADJ/GND), U7.3 (A1), U7.5 (A3), U7.7 (A5), U7.9 (A7), U7.10 (GND), U7.19 (OE#), U13.2 (-), U14.2 (-), U15.2 (-), U17.2 (-), USB1.0 (SH), USB1.1 (SH), USB1.2 (SH), USB1.3 (SH), USB1.A1 (GND), USB1.A12 (GND), USB1.B1 (GND), USB1.B12 (GND), USB2.4 (GND), USB2.8 (GND), USB2.9 (SHELL), USB2.10 (SHELL), USB2.11 (SHELL), USB2.12 (SHELL), USB3.8 (GND), USB3.9 (SHELL), USB3.10 (SHELL), USB3.11 (SHELL), USB3.12 (SHELL), USB5.0 (SH), USB5.1 (SH), USB5.2 (SH), USB5.3 (SH), USB5.A1 (GND), USB5.A12 (GND), USB5.B1 (GND), USB5.B12 (GND)
GPIO5: R20.2, U1.5 (IO5)
GPIO6: R11.2, U1.6 (IO6)
GPIO7: R14.2, U1.7 (IO7)
GPIO8: R13.2, U1.12 (IO8)
GPIO38: R19.2, U1.31 (IO38)
GSIG: R7.2, TP7.1, U1.29 (IO36)
MICLK: TP20.1, U1.25 (IO48), U5.4 (CLK)
MIDATA: TP21.1, U1.24 (IO47), U5.3 (DATA)
unnamed: BOOT1.3 (C), BOOT1.4 (D), R4.1
unnamed: Q1.1 (G), R5.1, R6.1
unnamed: Q2.1 (G), R7.1, R8.1
unnamed: Q3.1 (G), R9.1, R10.1
unnamed: U2.1 (+), U16.1
unnamed: R12.1, U3.1 (+)
unnamed: R13.1, U4.1 (+)
unnamed: R15.1, U7.18 (B0), U8.1
unnamed: R16.1, U7.16 (B2), U9.1
unnamed: R17.1, U7.14 (B4), U10.1
unnamed: R18.1, U7.12 (B6), U11.1
unnamed: R14.1, U13.1 (+)
unnamed: R19.1, U14.1 (+)
unnamed: R20.1, U15.1 (+)
unnamed: R11.1, U17.1 (+)
unnamed: R2.1, USB1.A5 (CC1)
unnamed: R1.2, USB1.B5 (CC2)
R: Q1.3 (D), TP8.1, USB3.2 (D-)
RSIG: R5.2, TP5.1, U1.28 (IO35)
TOUCH1: TP16.1, U1.39 (IO1)
TOUCH2: TP17.1, U1.38 (IO2)
TOUCH4: TP15.1, U1.4 (IO4)
USB_N: D1.1 (IO1), USB1.A7 (DN1), USB1.B7 (DN2)
USB_P: D1.3 (IO2), USB1.A6 (DP1), USB1.B6 (DP2)
VBUS: F1.1, USB1.A4 (VBUS), USB1.A9 (VBUS), USB1.B4 (VBUS), USB1.B9 (VBUS)

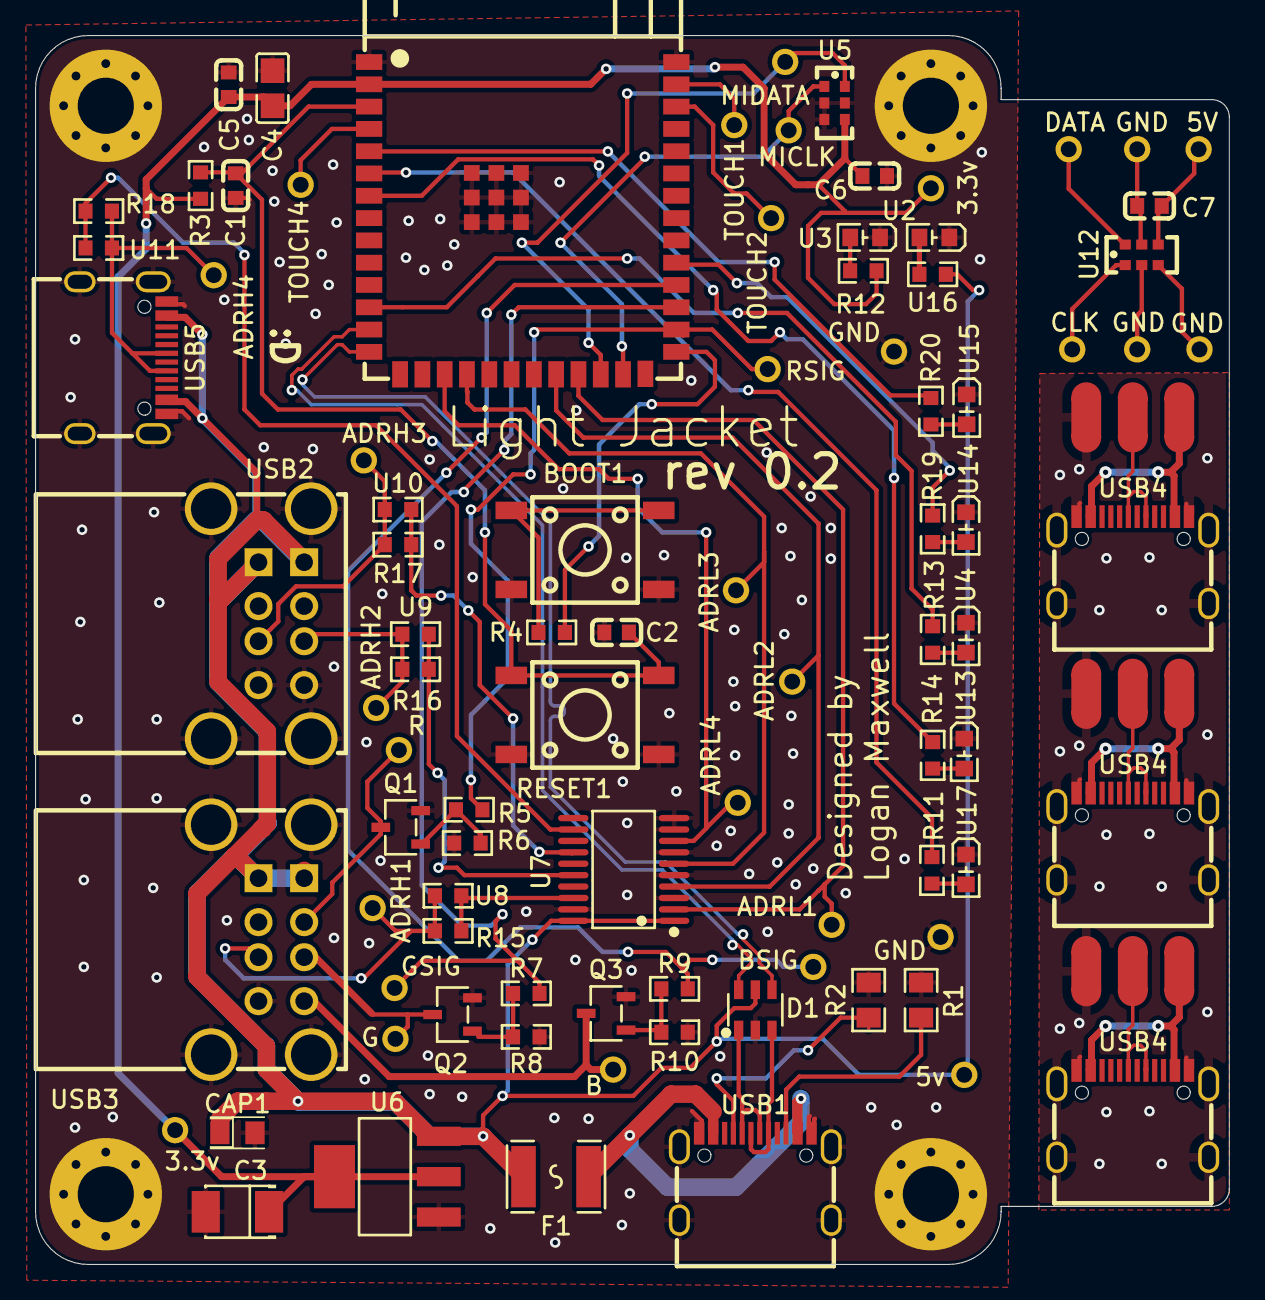
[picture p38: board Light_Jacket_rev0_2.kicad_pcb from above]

Board: 2 copper layers, 68.0 x 70.0 mm, 89 parts (0 on the bottom side), 60 nets.

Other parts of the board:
USB4#2, USB4#3: USB-C_SMD-TYPE-C-31-M-12

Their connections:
EXT5V: USB4#2.A4 (VBUS), USB4#2.A9 (VBUS), USB4#2.B4 (VBUS), USB4#2.B9 (VBUS), USB4#3.A4 (VBUS), USB4#3.A9 (VBUS), USB4#3.B4 (VBUS), USB4#3.B9 (VBUS); also elsewhere on the board
EXTDATA: USB4#2.A6 (DP1), USB4#2.B6 (DP2), USB4#3.A6 (DP1), USB4#3.B6 (DP2); also elsewhere on the board
EXTGND: USB4#2.0 (SH), USB4#2.1 (SH), USB4#2.2 (SH), USB4#2.3 (SH), USB4#2.A1 (GND), USB4#2.A12 (GND), USB4#2.B1 (GND), USB4#2.B12 (GND), USB4#3.0 (SH), USB4#3.1 (SH), USB4#3.2 (SH), USB4#3.3 (SH), USB4#3.A1 (GND), USB4#3.A12 (GND), USB4#3.B1 (GND), USB4#3.B12 (GND); also elsewhere on the board

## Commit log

2026-03-17 Added v0.1 pcb files and images
    [BOM_LightJacketV0_1.xlsx]
2026-04-22 Added readme entries for early and late april. Also changed structure of PCB folder
    [BOM_LightJacketV0_1.xlsx, C0603_L1.6-W0.8-H0.8.step, C0805_L2.0-W1.3-H1.3.step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]
2026-04-25 Adding another table for first revision board
2026-05-18 PCB update mid may
